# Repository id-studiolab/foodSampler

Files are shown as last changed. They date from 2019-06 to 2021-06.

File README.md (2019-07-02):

# foodSampler
Food sampler is a project to collect user data about their food consumption.
It consist of a series of devices equipped with buttons who can send and save data to a server using Lora protocol.

## The device
The devices are based on adafruit feather lora baord, and make use of a custom pcb.
They run on buttery and try to send messages to the lora network every 10 minutes.
once a button is pressed, they connect to the server and send out the data. A button cannot be pressed continuosly... a trasmission need to finish before a new message can be sent.
Arduino code, pcb design and more information on how to configure the library can be found inside the device folder.

## The server
The device communicate via a gateway to the things network, each device need to be configured and provisioned via ttn platform before it can send data to the server.
The server listens for incoming messages from the things network and saves the data to a mongodb DB. The data are accessible trough rest api.
More information on how to deploy the server and which api are accessible can be found in the server folder.

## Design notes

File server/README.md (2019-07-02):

# foodsempler
a node js server exposing rest api.

- use `npm install` to install the dependencies

- run the server with `npm run dev`

- update the apidoc using `gulp generateDoc`

- deploy to heroku with `git subtree push --prefix server/foodsampler/ heroku master`

## Usage
- Check [https://foodsampler.herokuapp.com/doc](https://foodsampler.herokuapp.com/doc) for a list of accessible api.
- All api requires the user to get an authorization token via the login api.
- The sign-up api is currently disabled, only the system administrator can create new accounts by re-enablyng the sign-up api and usin it to add new users to the DB.

## How to get the system ready for testing.
- use the api to create a new home.
- use the api to create new devices, make sure you define in which home the device will be added to

## How to chech the server logs
- login to heroku console and check if there are any error in the [console](https://dashboard.heroku.com/apps/foodsampler/logs)

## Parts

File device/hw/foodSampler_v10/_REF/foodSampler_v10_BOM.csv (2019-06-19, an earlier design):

Id | Designator | Package | Quantity | Designation | Supplier and ref
1 | J00 | PinHeader_1x16_P2.54mm_Vertical_SMD_Pin1Left | 1 | Conn_01x16
2 | C10,C20,C30,C40,C50,C60,C70,C80 | C_0603_1608Metric | 8 | 100nF
3 | R10,R20,R30,R40,R50,R60,R70,R03,R82,R04 | R_0603_1608Metric | 10 | 10K
4 | R11,R21,R31,R41,R51,R61,R71 | R_0603_1608Metric | 7 | 82R
5 | SW10,SW20,SW30,SW40,SW50,SW60,SW70 | MICRO_SW_LED | 7 | SWITCH_SPST_LED
6 | REF** | LIPO_3V7_2A_50x60 | 1 | LIPO_3V7_2A_50x60
7 | J01 | PinHeader_1x12_P2.54mm_Vertical_SMD_Pin1Left | 1 | Conn_01x12
8 | R80,R81 | R_0603_1608Metric | 2 | 4K7
9 | U80 | SOIC-8_3.9x4.9mm_P1.27mm | 1 | DS3231MZ
10 | D00 | LED_1206_3216Metric | 1 | LED_Small
11 | BT80 | CH291-1220LF | 1 | Battery_Cell
12 | Q00 | SOT-23 | 1 | BSS138
13 | REF**,REF**,REF**,REF** | MountingHole_3.2mm_M3_DIN965 | 4 | MountingHole_3.2mm_M3_DIN965
14 | REF**,REF** | Fiducial_1mm_Dia_2.54mm_Outer_CopperBottom | 2 | Fiducial_1mm_Dia_2.54mm_Outer_CopperBottom
15 | G*** | TUDelft_15x5.9 | 1 | LOGO
16 | REF** | OSHW-Logo_11.4x12mm_SilkScreen | 1 | OSHW-Logo_11.4x12mm_SilkScreen
17 | G*** | TUDelft_22.5x8.8 | 1 | LOGO

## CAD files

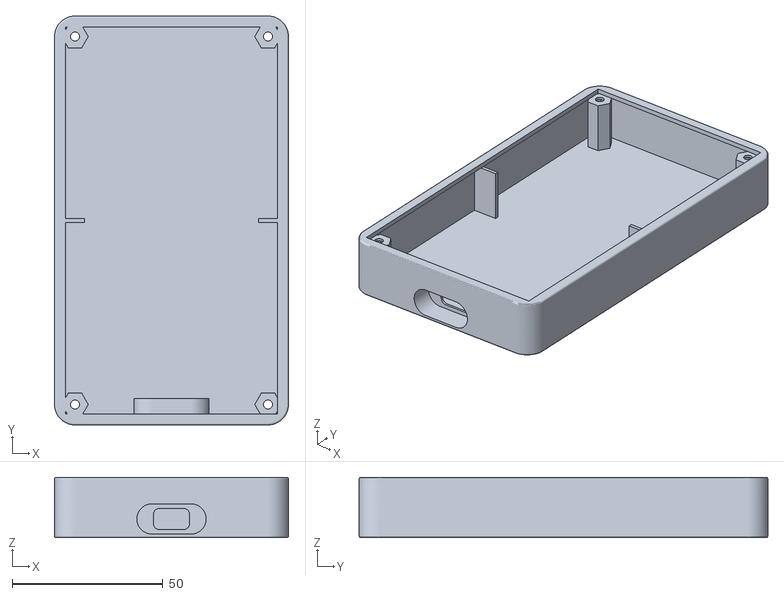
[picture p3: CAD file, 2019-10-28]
device/case/rev3.stl
77.6 x 135.6 x 20.0

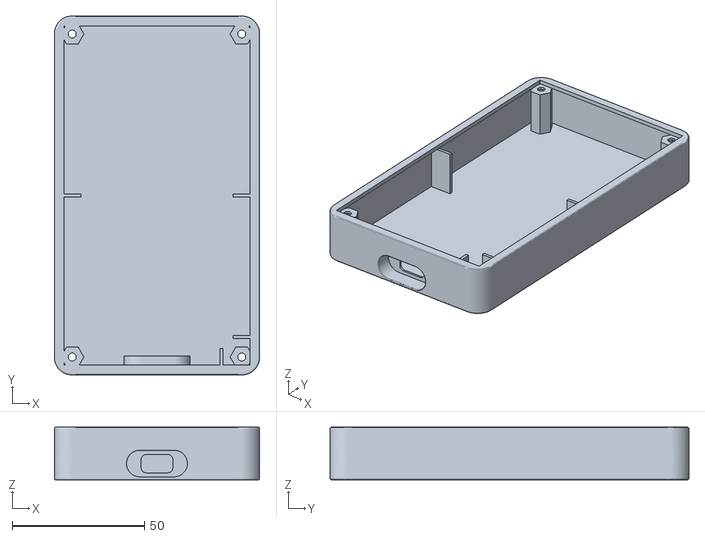
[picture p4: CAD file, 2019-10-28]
device/case/rev3c.stl
77.6 x 135.6 x 20.0

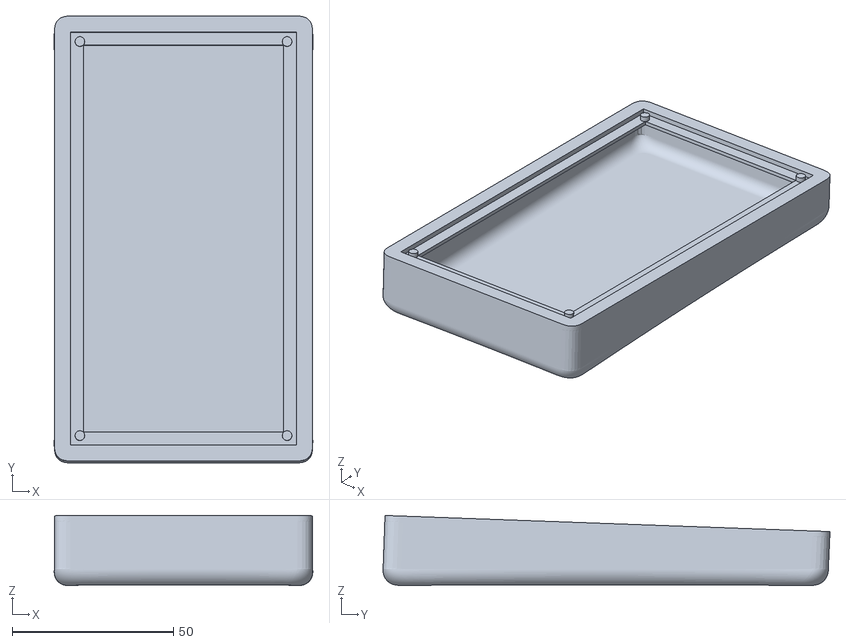
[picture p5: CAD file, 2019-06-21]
device/case/foodsampler.stl
80.1 x 138.5 x 21.7

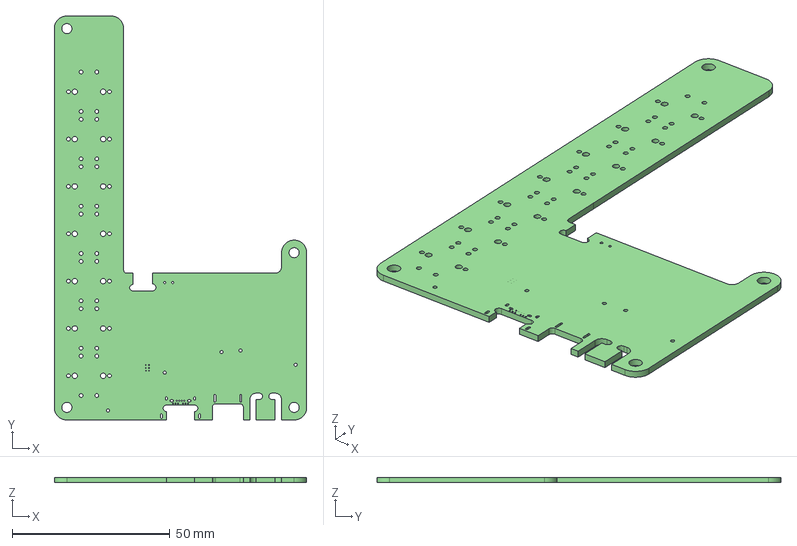
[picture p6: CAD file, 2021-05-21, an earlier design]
device/hw/foodSampler_v21/_REF/foodSampler_v21.step
80.0 x 128.0 x 1.60 mm

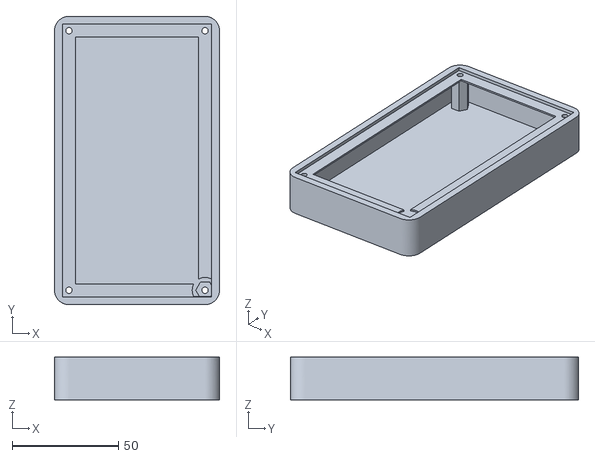
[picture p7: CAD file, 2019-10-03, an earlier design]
device/case/rev2.stl
77.6 x 135.6 x 20.0

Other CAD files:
device/case/rev3b.stl
device/case/rev3c.3dm

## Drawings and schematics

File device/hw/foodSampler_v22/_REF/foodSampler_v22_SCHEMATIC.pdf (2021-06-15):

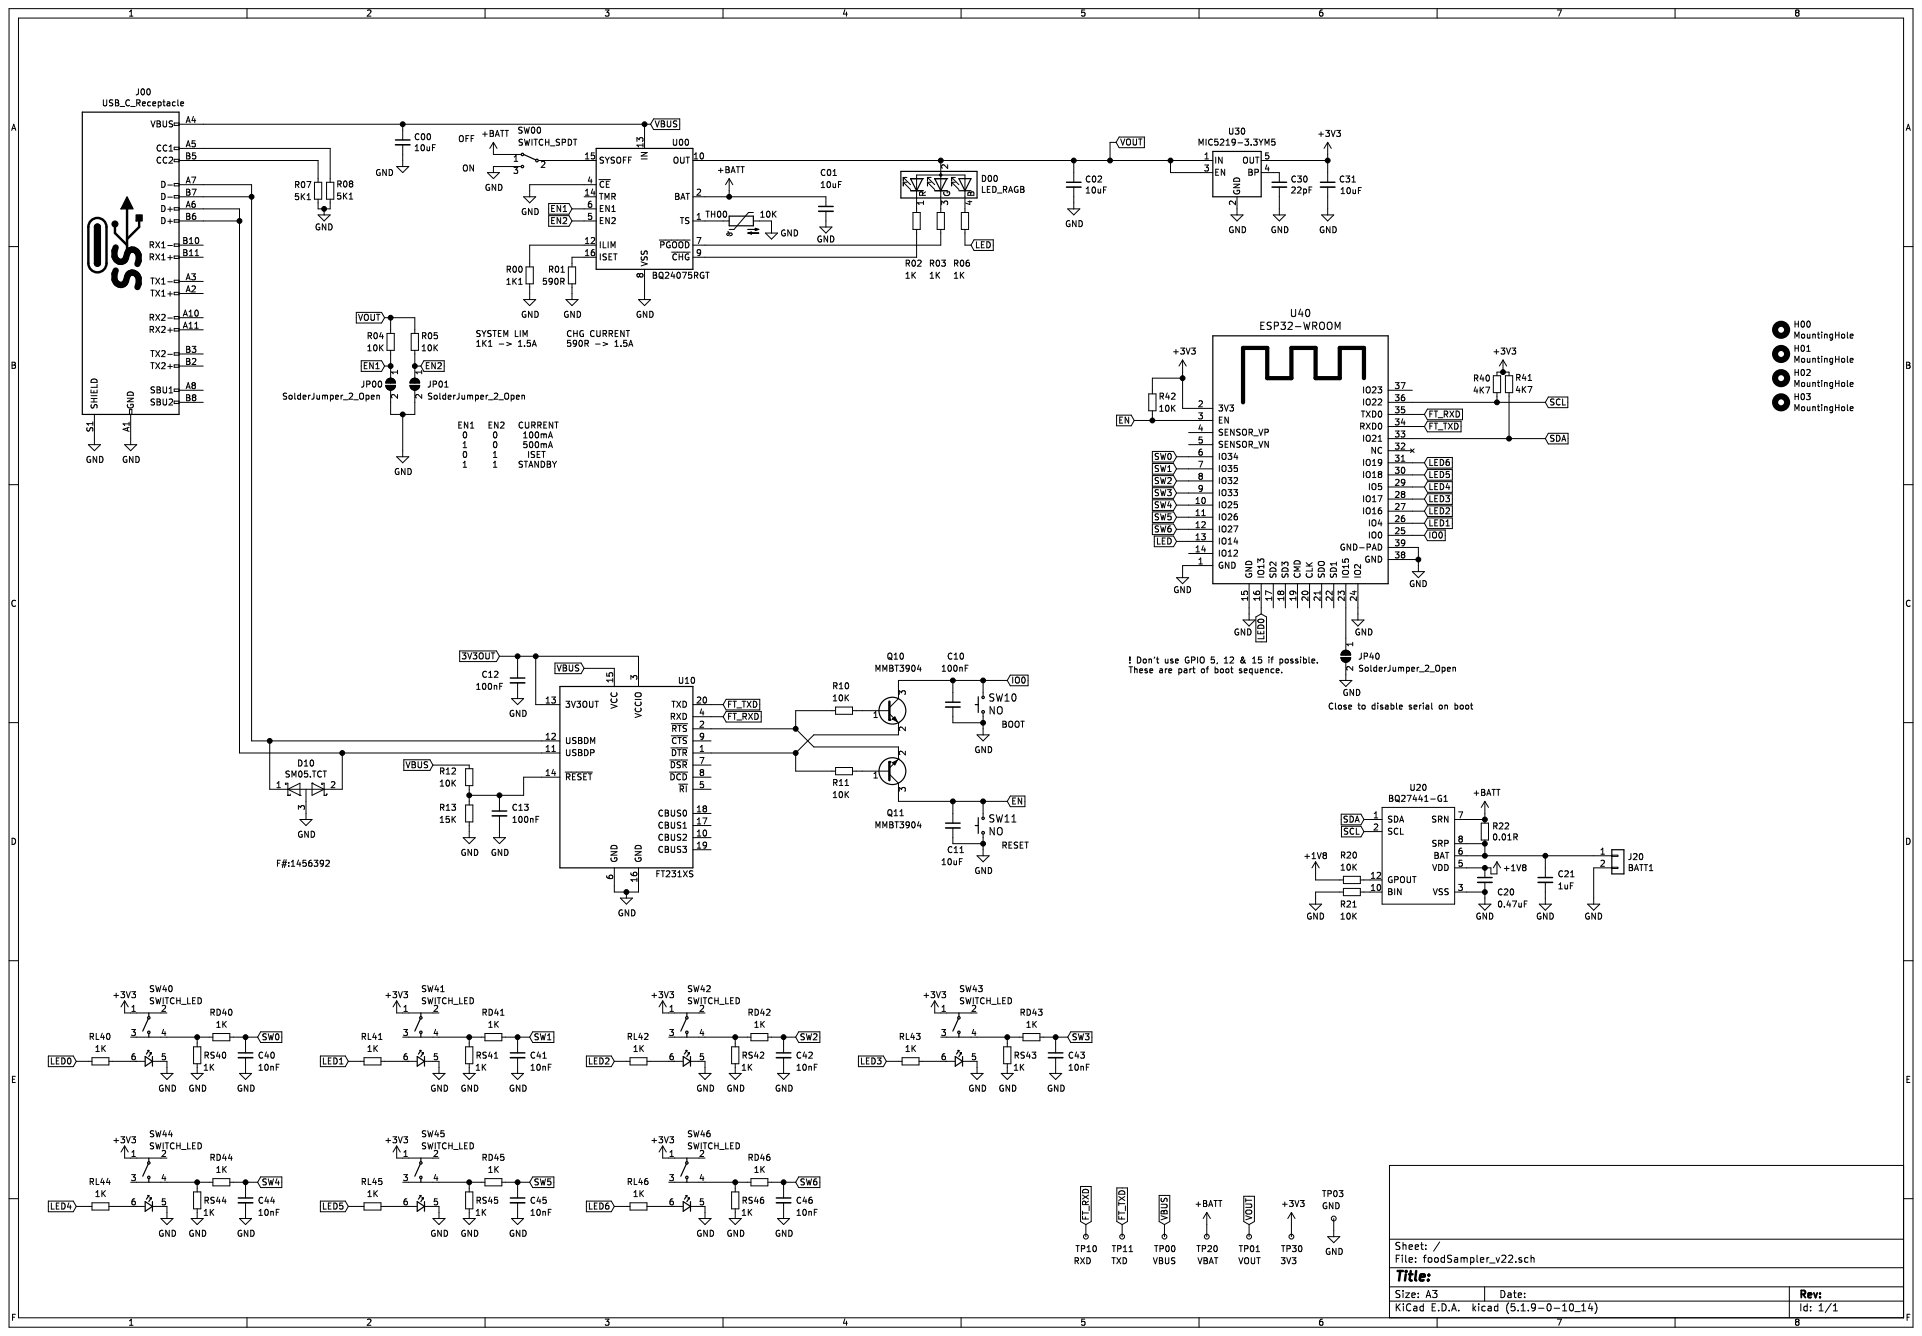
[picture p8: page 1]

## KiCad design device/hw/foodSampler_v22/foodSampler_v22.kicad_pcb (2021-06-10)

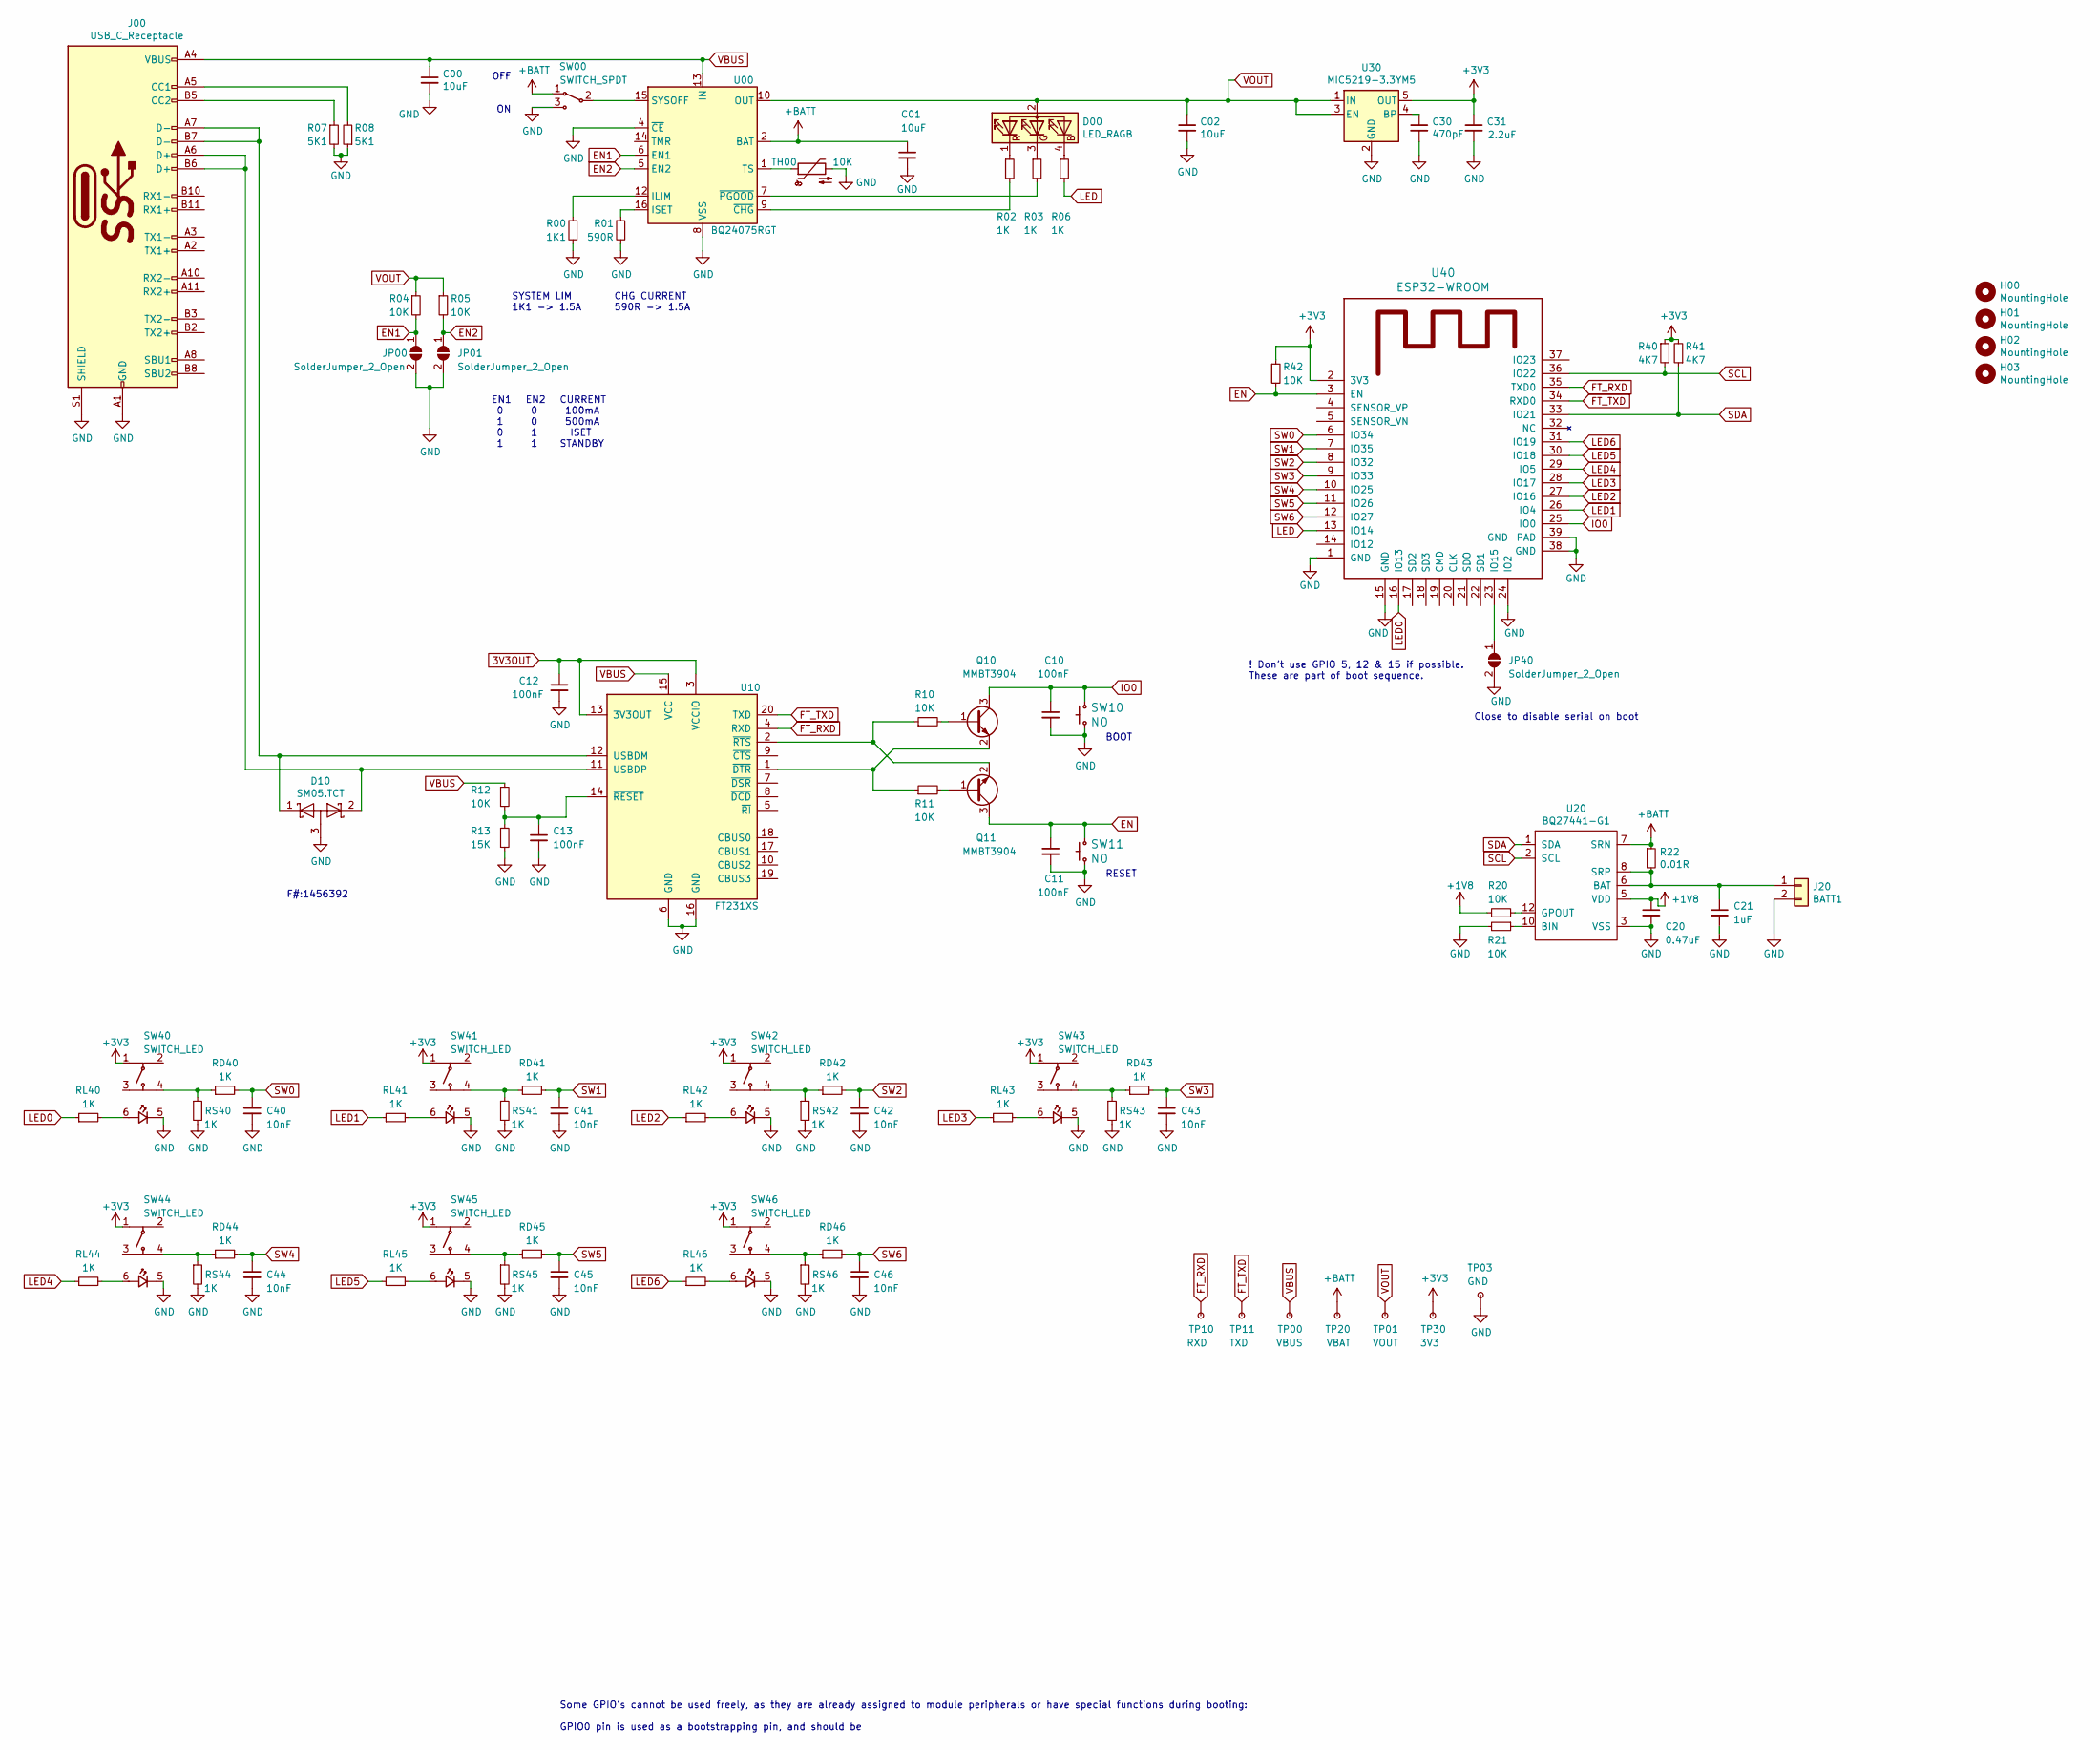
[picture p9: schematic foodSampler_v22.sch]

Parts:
C00, C01, C02: 10uF; C_0805_2012Metric
C10, C11, C12, C13: 100nF; C_0603_1608Metric
C20: 0.47uF; C_0603_1608Metric
C21: 1uF; C_0603_1608Metric
C30: 470pF; C_0603_1608Metric
C31: 2.2uF; CP_EIA-3216-10_Kemet-I
C40, C41, C42, C43, C44, C45, C46: 10nF; C_0603_1608Metric
D00: LED_RAGB; SMD_RGB_SIDE-APFA3010LSEEZGKQBKC
D10: SM05.TCT; SOT-23
H00, H01, H02, H03: MountingHole; MountingHole_3.2mm_M3
J00: USB_C_Receptacle; 632723130112
J20: BATT1; JST_B2B-PH-K-S_SUNK
JP00, JP01, JP40: SolderJumper_2_Open; SolderJumper-2_P1.3mm_Open_RoundedPad1.0x1.5mm
Q10, Q11: MMBT3904; SOT-23
R00: 1K1; R_0603_1608Metric
R01: 590R; R_0603_1608Metric
R02, R03, R06: 1K; R_0603_1608Metric
R04, R05, R10, R11, R12, R20, R21, R42: 10K; R_0603_1608Metric
R07, R08: 5K1; R_0603_1608Metric
R13: 15K; R_0603_1608Metric
R22: 0.01R; R_1210_3225Metric
R40, R41: 4K7; R_0603_1608Metric
RD40, RD41, RD42, RD43, RD44, RD45, RD46: 1K; R_0603_1608Metric
RL40, RL41, RL42, RL43, RL44, RL45, RL46: 1K; R_0603_1608Metric
RS40, RS41, RS42, RS43, RS44, RS45, RS46: 1K; R_0603_1608Metric
SW00: SWITCH_SPDT; DT-SC12P-BQR
SW10, SW11: NO; SW_SPST_4x3
SW40, SW41, SW42, SW43, SW44, SW45, SW46: SWITCH_LED; MICRO_SW_LED
TH00: 10K; R_Axial_DIN0204_L3.6mm_D1.6mm_P2.54mm_Vertical
TP00: VBUS; TEST_PAD_HOLE_1mm
TP01: VOUT; TEST_PAD_HOLE_1mm
TP03: GND; TEST_PAD_HOLE_1mm
TP10: RXD; TEST_PAD_HOLE_1mm
TP11: TXD; TEST_PAD_HOLE_1mm
TP20: VBAT; TEST_PAD_HOLE_1mm
TP30: 3V3; TEST_PAD_HOLE_1mm
U00: BQ24075RGT; VQFN-16-1EP_3x3mm_P0.5mm_EP1.6x1.6mm
U10: FT231XS; SSOP-20_3.9x8.7mm_P0.635mm
U20: BQ27441-G1; Texas_S-PDSO-N12
U30: MIC5219-3.3YM5; SOT-23-5
U40: ESP32-WROOM; ESP32-WROOM-32

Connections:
3V3OUT: C12.1, U10.3 (VCCIO), U10.13 (3V3OUT)
+1V8: C20.1, R20.1, U20.5 (VDD)
+3V3: C31.1, R40.1, R41.2, R42.1, SW40.1, SW41.1, SW42.1, SW43.1, SW44.1, SW45.1, SW46.1, TP30.1, U30.5 (OUT), U40.2 (3V3)
+BATT: C01.1, R22.1, SW00.1, TP20.1, U00.2 (BAT), U00.3 (BAT), U20.7 (SRN)
EN: C11.1, Q11.3 (C), R42.2, SW11.2 (B0), U40.3 (EN)
EN1: JP00.1 (A), R04.2, U00.6 (EN1)
EN2: JP01.1 (A), R05.2, U00.5 (EN2)
FT_RXD: TP10.1, U10.4 (RXD), U40.35 (TXD0)
FT_TXD: TP11.1, U10.20 (TXD), U40.34 (RXD0)
GND: C00.2, C01.2, C02.2, C10.2, C11.2, C12.2, C13.2, C20.2, C21.2, C30.2, C31.2, C40.2, C41.2, C42.2, C43.2, C44.2, C45.2, C46.2, D10.3 (A), J00.A1 (GND), J00.A12 (GND), J00.B1 (GND), J00.B12 (GND), J00.S1 (SHIELD), J20.2, JP00.2 (B), JP01.2 (B), JP40.2 (B), R00.2, R01.2, R07.2, R08.1, R13.2, R21.2, RS40.2, RS41.2, RS42.2, RS43.2, RS44.2, RS45.2, RS46.2, SW00.3, SW10.1 (A0), SW11.1 (A0), SW40.5, SW41.5, SW42.5, SW43.5, SW44.5, SW45.5, SW46.5, TH00.2, TP03.1, U00.4 (~CE), U00.8 (VSS), U00.17 (VSS), U10.6 (GND), U10.16 (GND), U20.3 (VSS), U30.2 (GND), U40.1 (GND), U40.15 (GND), U40.24 (IO2), U40.38 (GND), U40.39 (GND-PAD)
IO0: C10.1, Q10.3 (C), SW10.2 (B0), U40.25 (IO0)
LED: R06.2, U40.13 (IO14)
LED0: RL40.1, U40.16 (IO13)
LED1: RL41.1, U40.26 (IO4)
LED2: RL42.1, U40.27 (IO16)
LED3: RL43.1, U40.28 (IO17)
LED4: RL44.1, U40.29 (IO5)
LED5: RL45.1, U40.30 (IO18)
LED6: RL46.1, U40.31 (IO19)
unnamed: C13.1, R12.2, R13.1, U10.14 (~RESET)
unnamed: C21.1, J20.1, R22.2, U20.6 (BAT), U20.8 (SRP)
unnamed: C30.1, U30.4 (BP)
unnamed: D00.1 (RK), R02.1
unnamed: D00.3 (GK), R03.1
unnamed: D00.4 (BK), R06.1
unnamed: D10.1 (K), J00.A7 (D-), J00.B7 (D-), U10.12 (USBDM)
unnamed: D10.2 (K), J00.A6 (D+), J00.B6 (D+), U10.11 (USBDP)
unnamed: J00.A5 (CC1), R08.2
unnamed: J00.B5 (CC2), R07.1
unnamed: JP40.1 (A), U40.23 (IO15)
unnamed: Q10.1 (B), R10.2
unnamed: Q10.2 (E), R11.1, U10.1 (~DTR)
unnamed: Q11.1 (B), R11.2
unnamed: Q11.2 (E), R10.1, U10.2 (~RTS)
unnamed: R00.1, U00.12 (ILIM)
unnamed: R01.1, U00.16 (ISET)
unnamed: R02.2, U00.9 (~CHG)
unnamed: R03.2, U00.7 (~PGOOD)
unnamed: R20.2, U20.12 (GPOUT)
unnamed: R21.1, U20.10 (BIN)
unnamed: RD40.1, RS40.1, SW40.4
unnamed: RD41.1, RS41.1, SW41.4
unnamed: RD42.1, RS42.1, SW42.4
unnamed: RD43.1, RS43.1, SW43.4
unnamed: RD44.1, RS44.1, SW44.4
unnamed: RD45.1, RS45.1, SW45.4
unnamed: RD46.1, RS46.1, SW46.4
unnamed: RL40.2, SW40.6
unnamed: RL41.2, SW41.6
unnamed: RL42.2, SW42.6
unnamed: RL43.2, SW43.6
unnamed: RL44.2, SW44.6
unnamed: RL45.2, SW45.6
unnamed: RL46.2, SW46.6
unnamed: SW00.2, U00.15 (SYSOFF)
unnamed: TH00.1, U00.1 (TS)
SCL: R40.2, U20.2 (SCL), U40.36 (IO22)
SDA: R41.1, U20.1 (SDA), U40.33 (IO21)
SW0: C40.1, RD40.2, U40.6 (IO34)
SW1: C41.1, RD41.2, U40.7 (IO35)
SW2: C42.1, RD42.2, U40.8 (IO32)
SW3: C43.1, RD43.2, U40.9 (IO33)
SW4: C44.1, RD44.2, U40.10 (IO25)
SW5: C45.1, RD45.2, U40.11 (IO26)
SW6: C46.1, RD46.2, U40.12 (IO27)
VBUS: C00.1, J00.A4 (VBUS), J00.A9 (VBUS), J00.B4 (VBUS), J00.B9 (VBUS), R12.1, TP00.1, U00.13 (IN), U10.15 (VCC)
VOUT: C02.1, D00.2 (A), R04.1, R05.1, TP01.1, U00.10 (OUT), U00.11 (OUT), U30.1 (IN), U30.3 (EN)

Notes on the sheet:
F#:1456392
RESET
BOOT
! Don’t use GPIO 5, 12 & 15 if possible. These are part of boot sequence.
CHG CURRENT 590R -> 1.5A
SYSTEM LIM 1K1 -> 1.5A
EN1 0 1 0 1
EN2 0 0 1 1
CURRENT 100mA 500mA ISET STANDBY
OFF ON
Some GPIO’s cannot be used freely, as they are already assigned to module peripherals or have special functions during booting: GPIO0 pin is used as a bootstrapping pin, and should be low to enter UART download mode. Make sure it is not pulled low by a peripheral device during boot or the firmware 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
Close to disable serial on boot

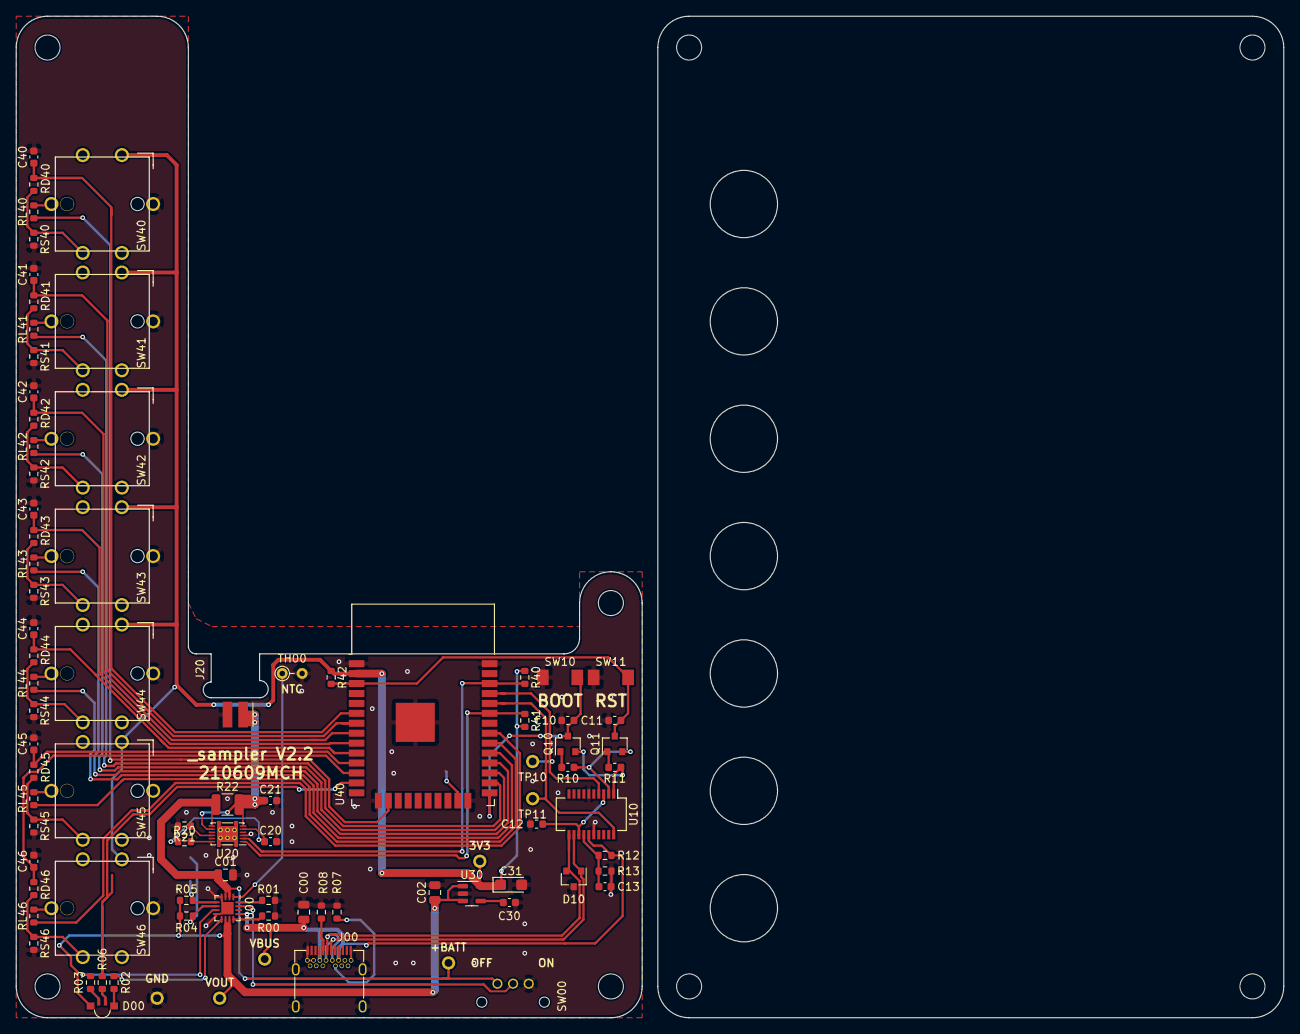
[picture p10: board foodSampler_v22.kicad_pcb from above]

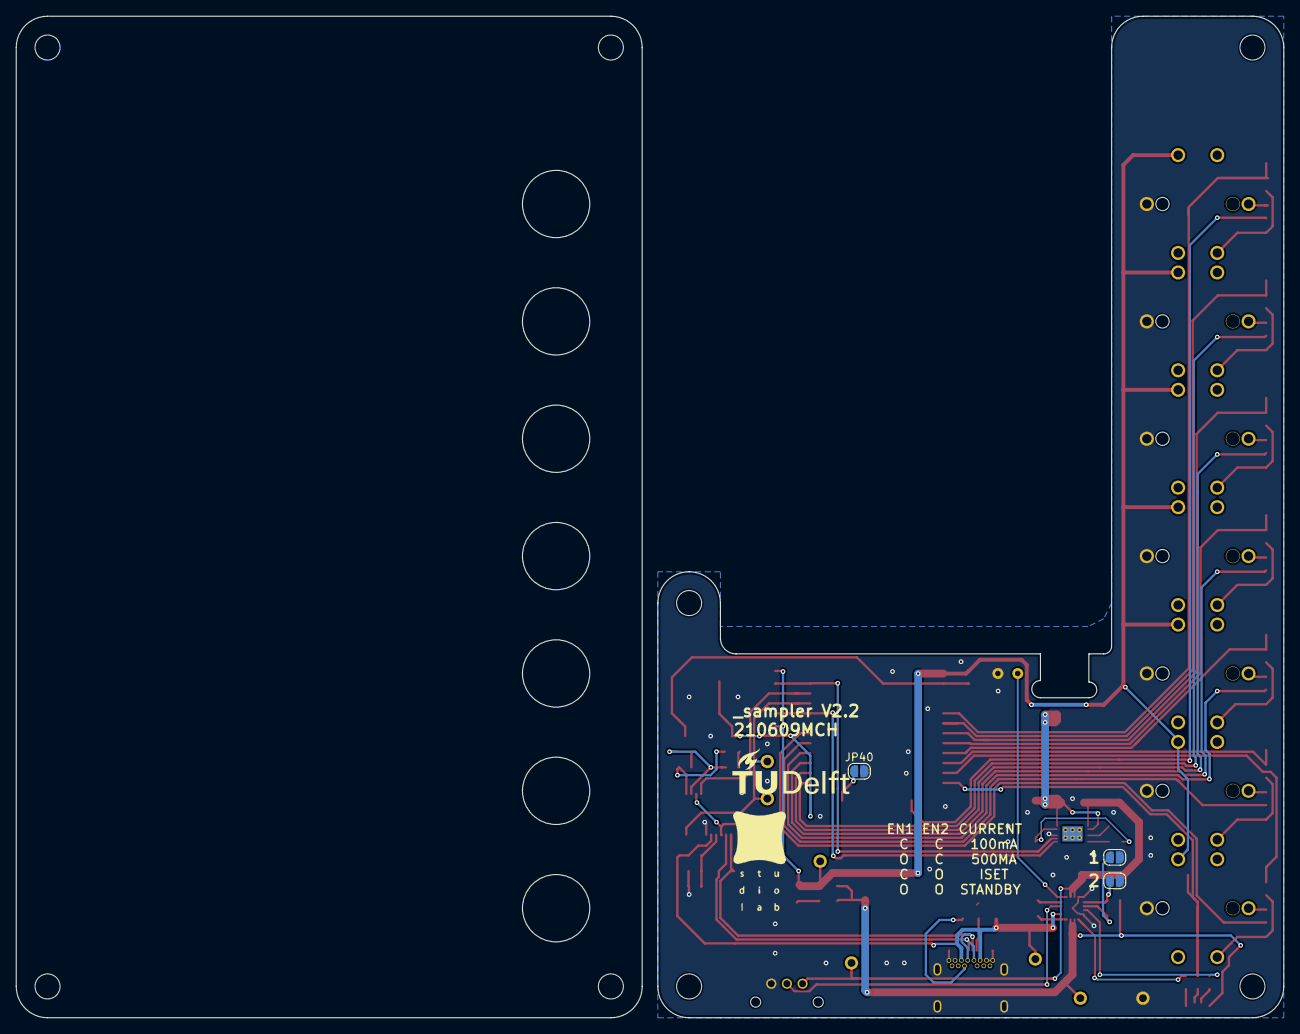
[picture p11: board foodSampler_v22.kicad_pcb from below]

Board: 2 copper layers, 162.0 x 128.0 mm, 98 parts (3 on the bottom side), 67 nets.

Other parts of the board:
H01#2, H01#3, H01#4, H01#5: MountingHole; MountingHole_3.2mm_M3

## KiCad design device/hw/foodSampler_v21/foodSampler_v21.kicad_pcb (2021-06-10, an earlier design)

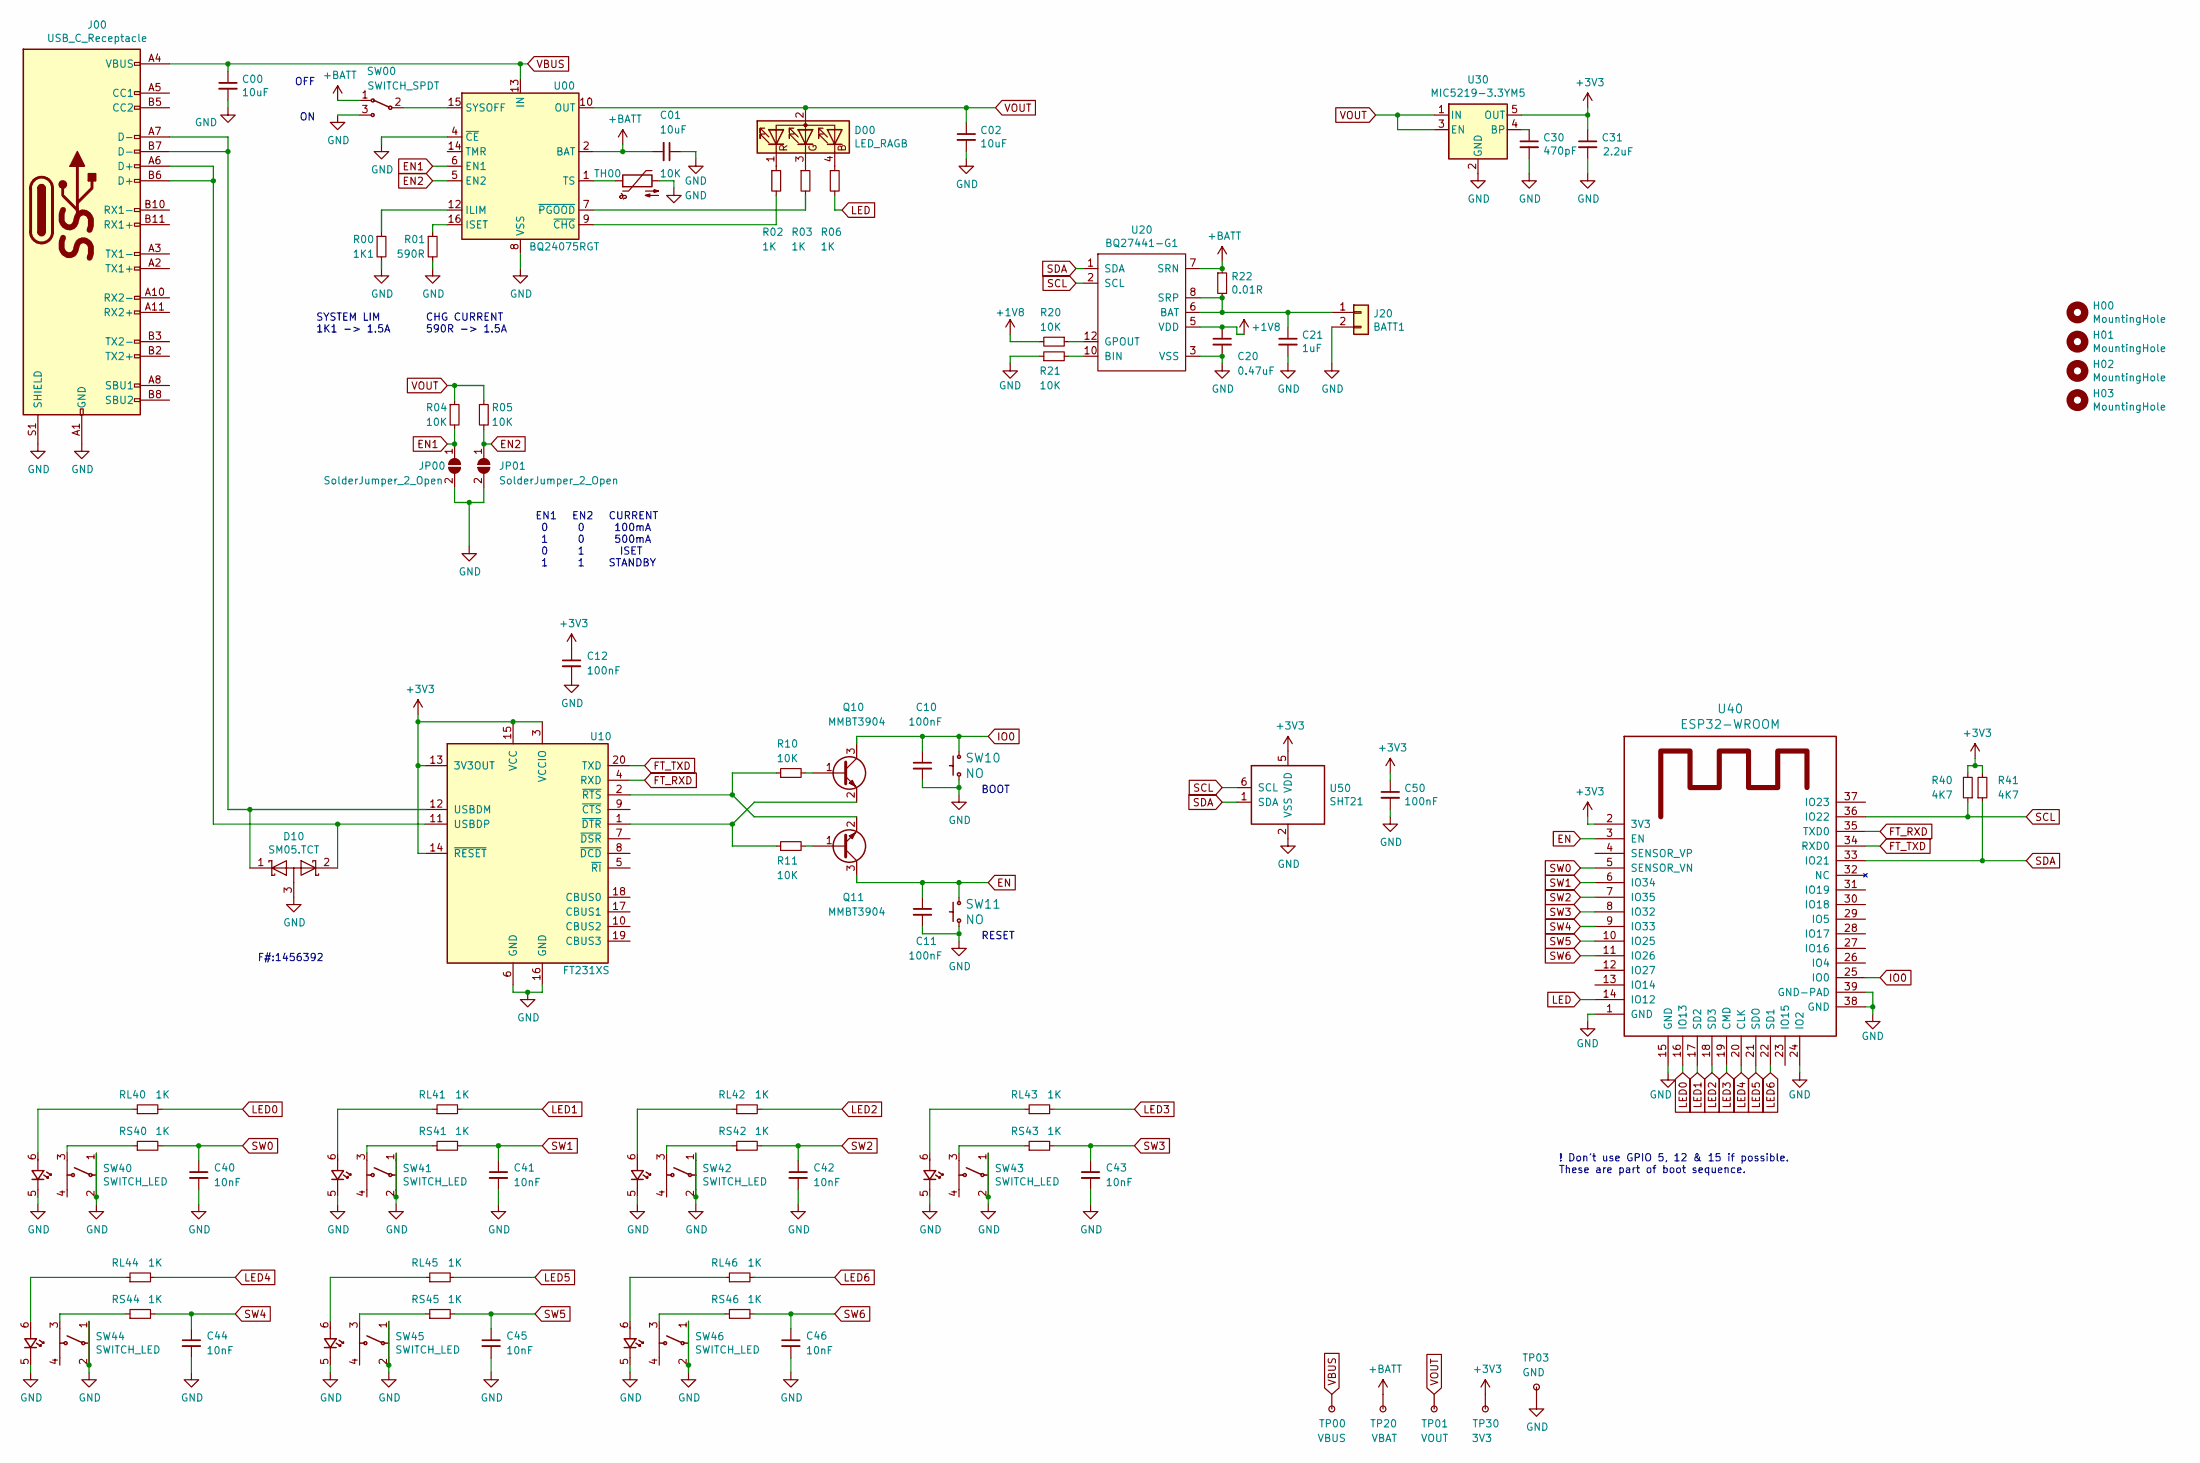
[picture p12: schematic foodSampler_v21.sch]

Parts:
C00, C01, C02: 10uF; C_0805_2012Metric
C10, C11, C12, C50: 100nF; C_0603_1608Metric
C20: 0.47uF; C_0603_1608Metric
C21: 1uF; C_0603_1608Metric
C30: 470pF; C_0603_1608Metric
C31: 2.2uF; CP_EIA-3216-10_Kemet-I
C40, C41, C42, C43, C44, C45, C46: 10nF; C_0603_1608Metric
D00: LED_RAGB; SMD_RGB_SIDE-APFA3010LSEEZGKQBKC
D10: SM05.TCT; SOT-23
H00, H01, H02, H03: MountingHole; MountingHole_3.2mm_M3
J00: USB_C_Receptacle; CUI_USB-C_UJ31-CH-3-MSMT-TR-67
J20: BATT1; JST_B2B-PH-K-S_SUNK
JP00, JP01: SolderJumper_2_Open; SolderJumper-2_P1.3mm_Open_RoundedPad1.0x1.5mm
Q10, Q11: MMBT3904; SOT-23
R00: 1K1; R_0603_1608Metric
R01: 590R; R_0603_1608Metric
R02, R03, R06: 1K; R_0603_1608Metric
R04, R05, R10, R11, R20, R21: 10K; R_0603_1608Metric
R22: 0.01R; C_1206_3216Metric
R40, R41: 4K7; R_0603_1608Metric
RL40, RL41, RL42, RL43, RL44, RL45, RL46: 1K; R_0603_1608Metric
RS40, RS41, RS42, RS43, RS44, RS45, RS46: 1K; R_0603_1608Metric
SW00: SWITCH_SPDT; C&K-OS102011MS2QN1_side_mount
SW10, SW11: NO; SW_SPST_4x3
SW40, SW41, SW42, SW43, SW44, SW45, SW46: SWITCH_LED; MICRO_SW_LED
TH00: 10K; R_Axial_DIN0204_L3.6mm_D1.6mm_P2.54mm_Vertical
TP00: VBUS; TEST_PAD_HOLE_1mm
TP01: VOUT; TEST_PAD_HOLE_1mm
TP03: GND; TEST_PAD_HOLE_1mm
TP20: VBAT; TEST_PAD_HOLE_1mm
TP30: 3V3; TEST_PAD_HOLE_1mm
U00: BQ24075RGT; VQFN-16-1EP_3x3mm_P0.5mm_EP1.6x1.6mm
U10: FT231XS; SSOP-20_3.9x8.7mm_P0.635mm
U20: BQ27441-G1; Texas_S-PDSO-N12
U30: MIC5219-3.3YM5; SOT-23-5
U40: ESP32-WROOM; ESP32-WROOM-32
U50: SHT21

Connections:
+1V8: C20.1, R20.2, U20.5 (VDD)
+3V3: C12.1, C31.1, C50.1, R40.2, R41.2, TP30.1, U10.3 (VCCIO), U10.13 (3V3OUT), U10.14 (~RESET), U10.15 (VCC), U30.5 (OUT), U40.2 (3V3), U50.5 (VDD)
+BATT: C01.2, R22.1, SW00.1, TP20.1, U00.2 (BAT), U00.3 (BAT), U20.7 (SRN)
EN: C11.1, Q11.3 (C), SW11.2 (B0), U40.3 (EN)
EN1: JP00.1 (A), R04.2, U00.6 (EN1)
EN2: JP01.1 (A), R05.2, U00.5 (EN2)
FT_RXD: U10.4 (RXD), U40.35 (TXD0)
FT_TXD: U10.20 (TXD), U40.34 (RXD0)
GND: C00.2, C01.1, C02.2, C10.2, C11.2, C12.2, C20.2, C21.2, C30.2, C31.2, C40.2, C41.2, C42.2, C43.2, C44.2, C45.2, C46.2, C50.2, D10.3 (A), J00.A1 (GND), J00.A12 (GND), J00.B1 (GND), J00.B12 (GND), J00.S1 (SHIELD), J20.2, JP00.2 (B), JP01.2 (B), R00.2, R01.2, R21.1, SW00.3, SW10.1 (A0), SW11.1 (A0), SW40.1, SW40.2, SW40.5, SW41.1, SW41.2, SW41.5, SW42.1, SW42.2, SW42.5, SW43.1, SW43.2, SW43.5, SW44.1, SW44.2, SW44.5, SW45.1, SW45.2, SW45.5, SW46.1, SW46.2, SW46.5, TH00.2, TP03.1, U00.4 (~CE), U00.8 (VSS), U00.17 (VSS), U10.6 (GND), U10.16 (GND), U20.3 (VSS), U30.2 (GND), U40.1 (GND), U40.15 (GND), U40.24 (IO2), U40.38 (GND), U40.39 (GND-PAD), U50.2 (VSS)
IO0: C10.1, Q10.3 (C), SW10.2 (B0), U40.25 (IO0)
LED: R06.2, U40.14 (IO12)
LED0: RL40.2, U40.16 (IO13)
LED1: RL41.2, U40.17 (SD2)
LED2: RL42.2, U40.18 (SD3)
LED3: RL43.2, U40.19 (CMD)
LED4: RL44.2, U40.20 (CLK)
LED5: RL45.2, U40.21 (SDO)
LED6: RL46.2, U40.22 (SD1)
unnamed: C21.1, J20.1, R22.2, U20.6 (BAT), U20.8 (SRP)
unnamed: C30.1, U30.4 (BP)
unnamed: D00.1 (RK), R02.1
unnamed: D00.3 (GK), R03.1
unnamed: D00.4 (BK), R06.1
unnamed: D10.1 (K), J00.A7 (D-), J00.B7 (D-), U10.12 (USBDM)
unnamed: D10.2 (K), J00.A6 (D+), J00.B6 (D+), U10.11 (USBDP)
unnamed: Q10.1 (B), R10.2
unnamed: Q10.2 (E), R11.1, U10.1 (~DTR)
unnamed: Q11.1 (B), R11.2
unnamed: Q11.2 (E), R10.1, U10.2 (~RTS)
unnamed: R00.1, U00.12 (ILIM)
unnamed: R01.1, U00.16 (ISET)
unnamed: R02.2, U00.9 (~CHG)
unnamed: R03.2, U00.7 (~PGOOD)
unnamed: R20.1, U20.12 (GPOUT)
unnamed: R21.2, U20.10 (BIN)
unnamed: RL40.1, SW40.6
unnamed: RL41.1, SW41.6
unnamed: RL42.1, SW42.6
unnamed: RL43.1, SW43.6
unnamed: RL44.1, SW44.6
unnamed: RL45.1, SW45.6
unnamed: RL46.1, SW46.6
unnamed: RS40.1, SW40.3
unnamed: RS41.1, SW41.3
unnamed: RS42.1, SW42.3
unnamed: RS43.1, SW43.3
unnamed: RS44.1, SW44.3
unnamed: RS45.1, SW45.3
unnamed: RS46.1, SW46.3
unnamed: SW00.2, U00.15 (SYSOFF)
unnamed: TH00.1, U00.1 (TS)
SCL: R40.1, U20.2 (SCL), U40.36 (IO22), U50.6 (SCL)
SDA: R41.1, U20.1 (SDA), U40.33 (IO21), U50.1 (SDA)
SW0: C40.1, RS40.2, U40.5 (SENSOR_VN)
SW1: C41.1, RS41.2, U40.6 (IO34)
SW2: C42.1, RS42.2, U40.7 (IO35)
SW3: C43.1, RS43.2, U40.8 (IO32)
SW4: C44.1, RS44.2, U40.9 (IO33)
SW5: C45.1, RS45.2, U40.10 (IO25)
SW6: C46.1, RS46.2, U40.11 (IO26)
VBUS: C00.1, J00.A4 (VBUS), J00.A9 (VBUS), J00.B4 (VBUS), J00.B9 (VBUS), TP00.1, U00.13 (IN)
VOUT: C02.1, D00.2 (A), R04.1, R05.1, TP01.1, U00.10 (OUT), U00.11 (OUT), U30.1 (IN), U30.3 (EN)

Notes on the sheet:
F#:1456392
RESET
BOOT
! Don’t use GPIO 5, 12 & 15 if possible. These are part of boot sequence.
CHG CURRENT 590R -> 1.5A
SYSTEM LIM 1K1 -> 1.5A
EN1 0 1 0 1
EN2 0 0 1 1
CURRENT 100mA 500mA ISET STANDBY
OFF ON

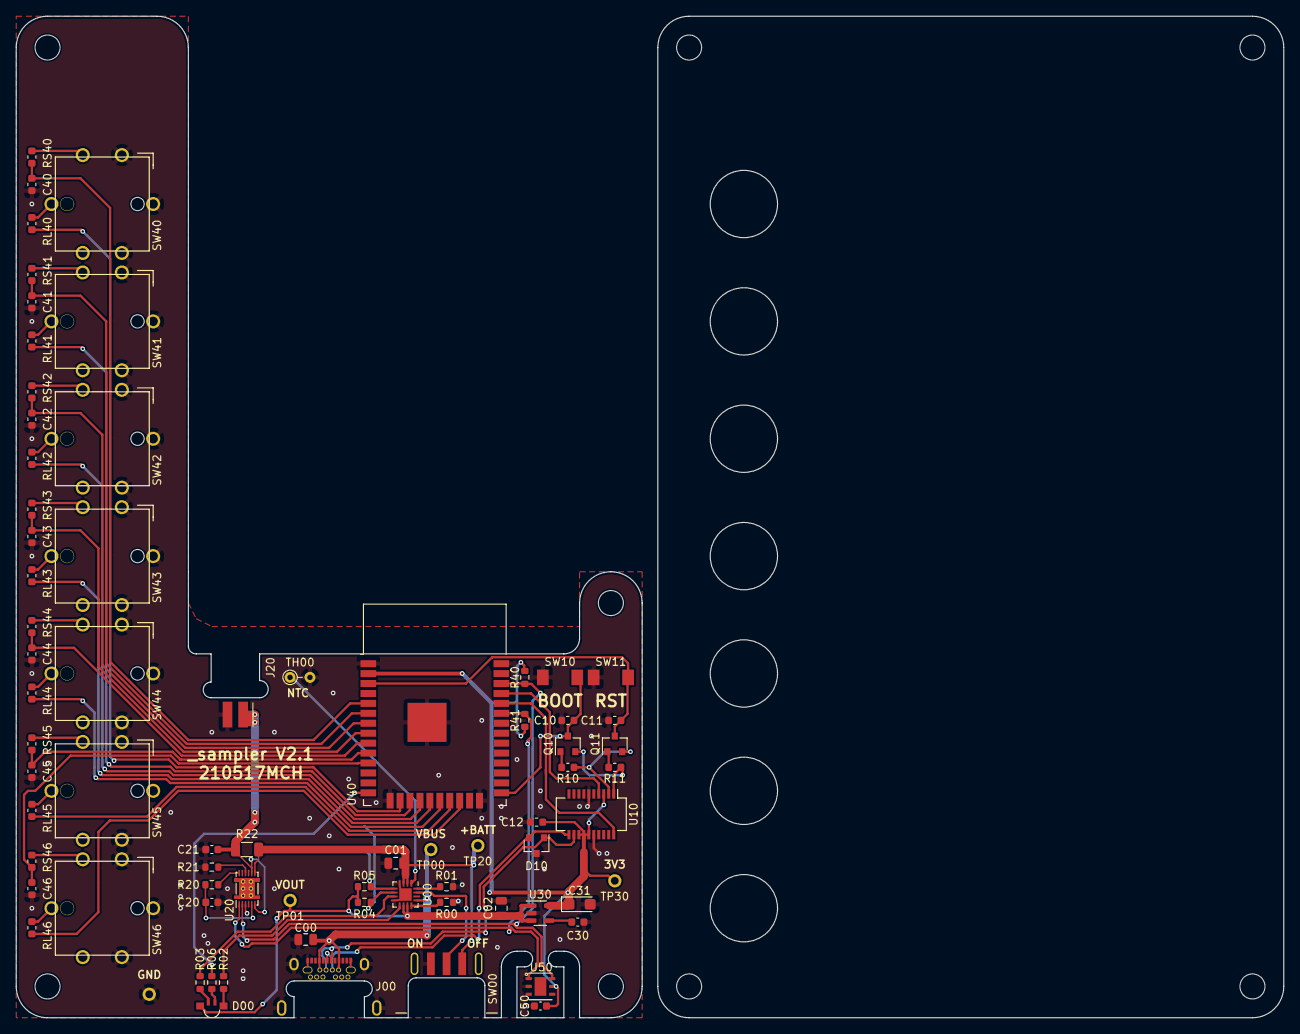
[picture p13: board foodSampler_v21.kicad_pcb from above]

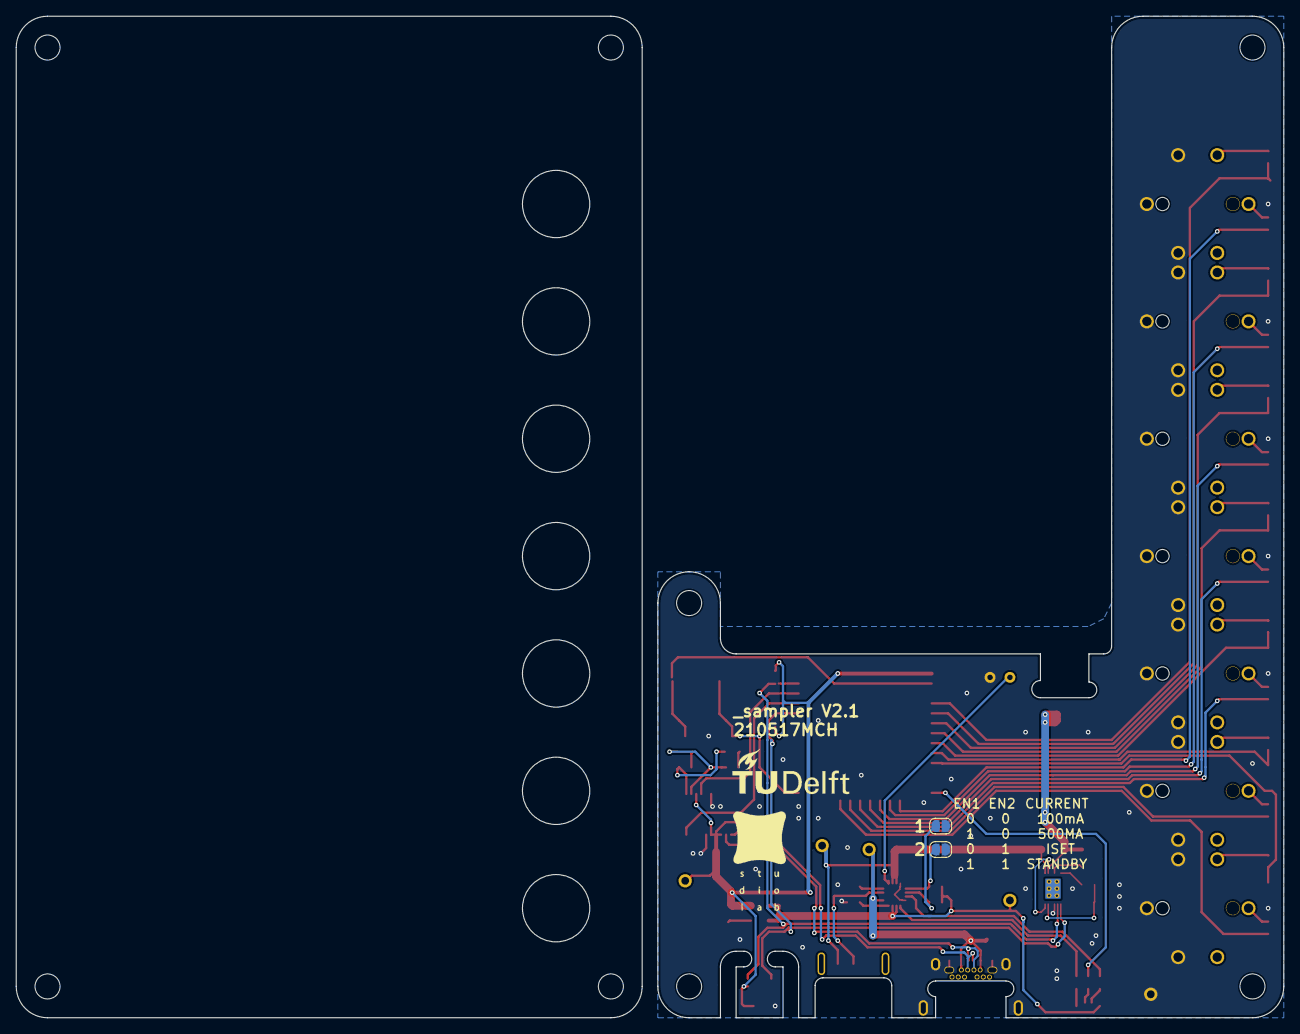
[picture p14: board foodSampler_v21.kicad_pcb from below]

Board: 2 copper layers, 162.0 x 128.0 mm, 84 parts (2 on the bottom side), 62 nets.

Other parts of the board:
H01#2, H01#3, H01#4, H01#5: MountingHole; MountingHole_3.2mm_M3

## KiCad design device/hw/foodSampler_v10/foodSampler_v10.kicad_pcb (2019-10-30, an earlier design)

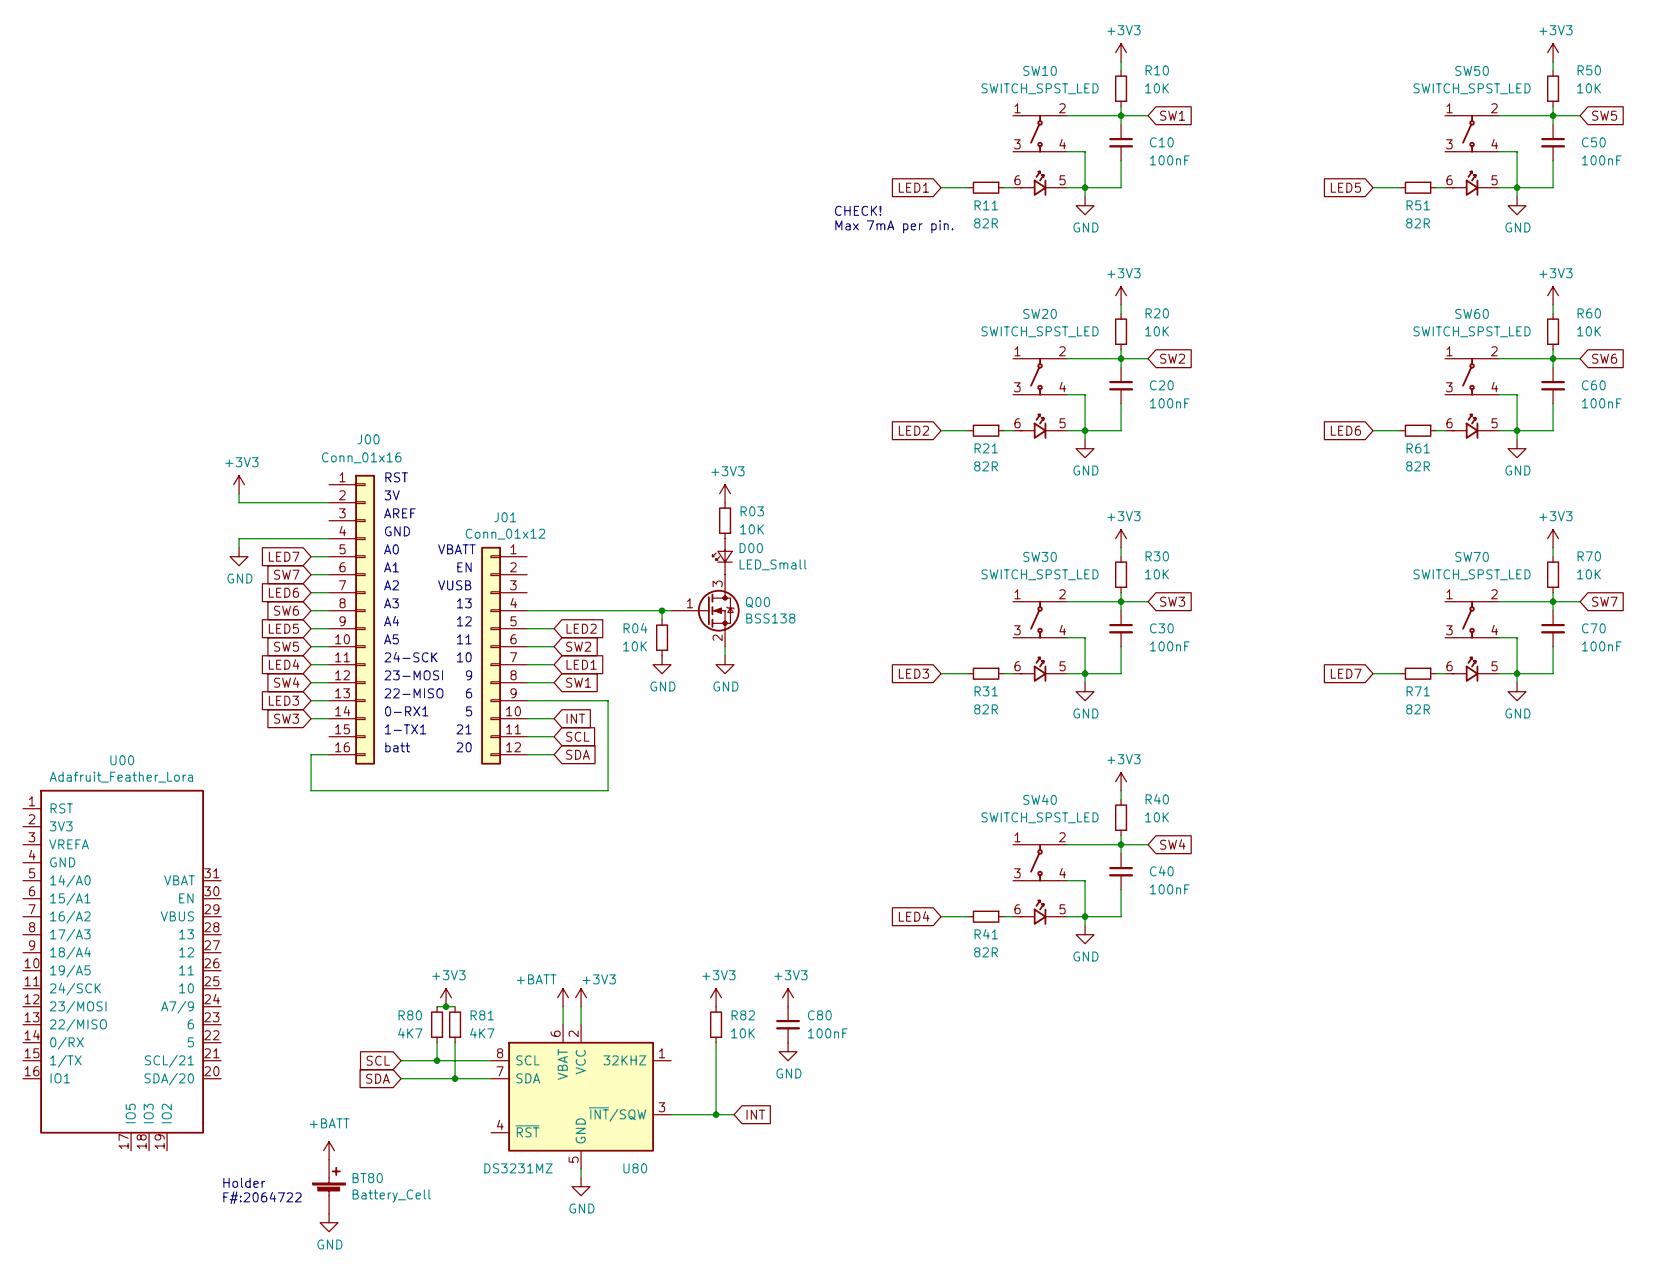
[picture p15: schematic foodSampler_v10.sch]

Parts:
BT80: Battery_Cell; CH291-1220LF
C10, C20, C30, C40, C50, C60, C70, C80: 100nF; C_0603_1608Metric
D00: LED_Small; LED_1206_3216Metric
J00: Conn_01x16; PinHeader_1x16_P2.54mm_Vertical_SMD_Pin1Left
J01: Conn_01x12; PinHeader_1x12_P2.54mm_Vertical_SMD_Pin1Left
Q00: BSS138; SOT-23
R03, R04, R10, R20, R30, R40, R50, R60, R70, R82: 10K; R_0603_1608Metric
R11, R21, R31, R41, R51, R61, R71: 82R; R_0603_1608Metric
R80, R81: 4K7; R_0603_1608Metric
SW10, SW20, SW30, SW40, SW50, SW60, SW70: SWITCH_SPST_LED; MICRO_SW_LED
U00: Adafruit_Feather_Lora; Adafruit Feather LORA
U80: DS3231MZ; SOIC-8_3.9x4.9mm_P1.27mm

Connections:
+3V3: C80.1, J00.2, R03.2, R10.2, R20.2, R30.2, R40.2, R50.2, R60.2, R70.2, R80.2, R81.2, R82.2, U80.2 (VCC)
+BATT: BT80.1 (+), U80.6 (VBAT)
GND: BT80.2 (-), C10.2, C20.2, C30.2, C40.2, C50.2, C60.2, C70.2, C80.2, J00.4, Q00.2 (S), R04.1, SW10.4, SW10.5, SW20.4, SW20.5, SW30.4, SW30.5, SW40.4, SW40.5, SW50.4, SW50.5, SW60.4, SW60.5, SW70.4, SW70.5, U80.5 (GND)
INT: J01.10, R82.1, U80.3 (~INT~/SQW)
LED1: J01.7, R11.2
LED2: J01.5, R21.2
LED3: J00.13, R31.2
LED4: J00.11, R41.2
LED5: J00.9, R51.2
LED6: J00.7, R61.2
LED7: J00.5, R71.2
unnamed: D00.1 (K), Q00.3 (D)
unnamed: D00.2 (A), R03.1
unnamed: J00.16, J01.9
unnamed: J01.4, Q00.1 (G), R04.2
unnamed: R11.1, SW10.6
unnamed: R21.1, SW20.6
unnamed: R31.1, SW30.6
unnamed: R41.1, SW40.6
unnamed: R51.1, SW50.6
unnamed: R61.1, SW60.6
unnamed: R71.1, SW70.6
SCL: J01.11, R80.1, U80.8 (SCL)
SDA: J01.12, R81.1, U80.7 (SDA)
SW1: C10.1, J01.8, R10.1, SW10.2
SW2: C20.1, J01.6, R20.1, SW20.2
SW3: C30.1, J00.14, R30.1, SW30.2
SW4: C40.1, J00.12, R40.1, SW40.2
SW5: C50.1, J00.10, R50.1, SW50.2
SW6: C60.1, J00.8, R60.1, SW60.2
SW7: C70.1, J00.6, R70.1, SW70.2

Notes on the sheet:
CHECK! Max 7mA per pin.
Holder F#:2064722
batt
1-TX1
0-RX1
22-MISO
23-MOSI
24-SCK
GND
AREF
RST
VUSB
VBATT

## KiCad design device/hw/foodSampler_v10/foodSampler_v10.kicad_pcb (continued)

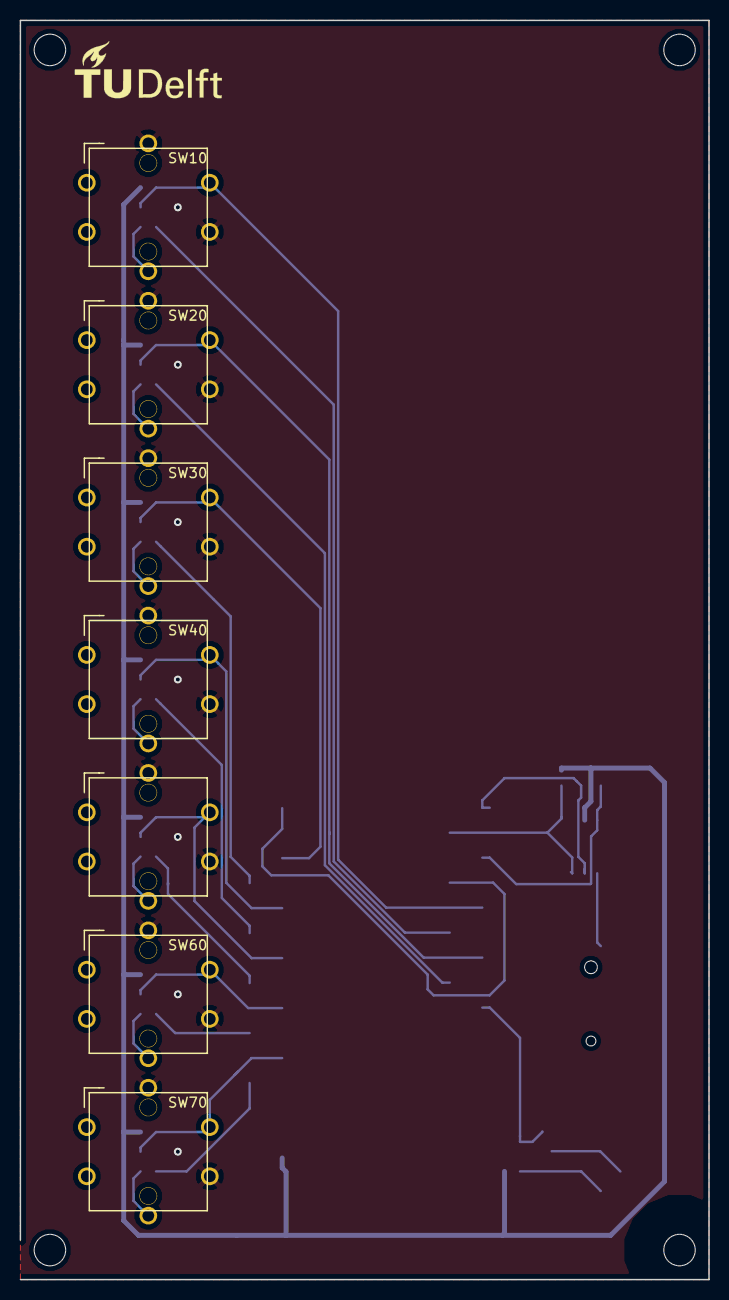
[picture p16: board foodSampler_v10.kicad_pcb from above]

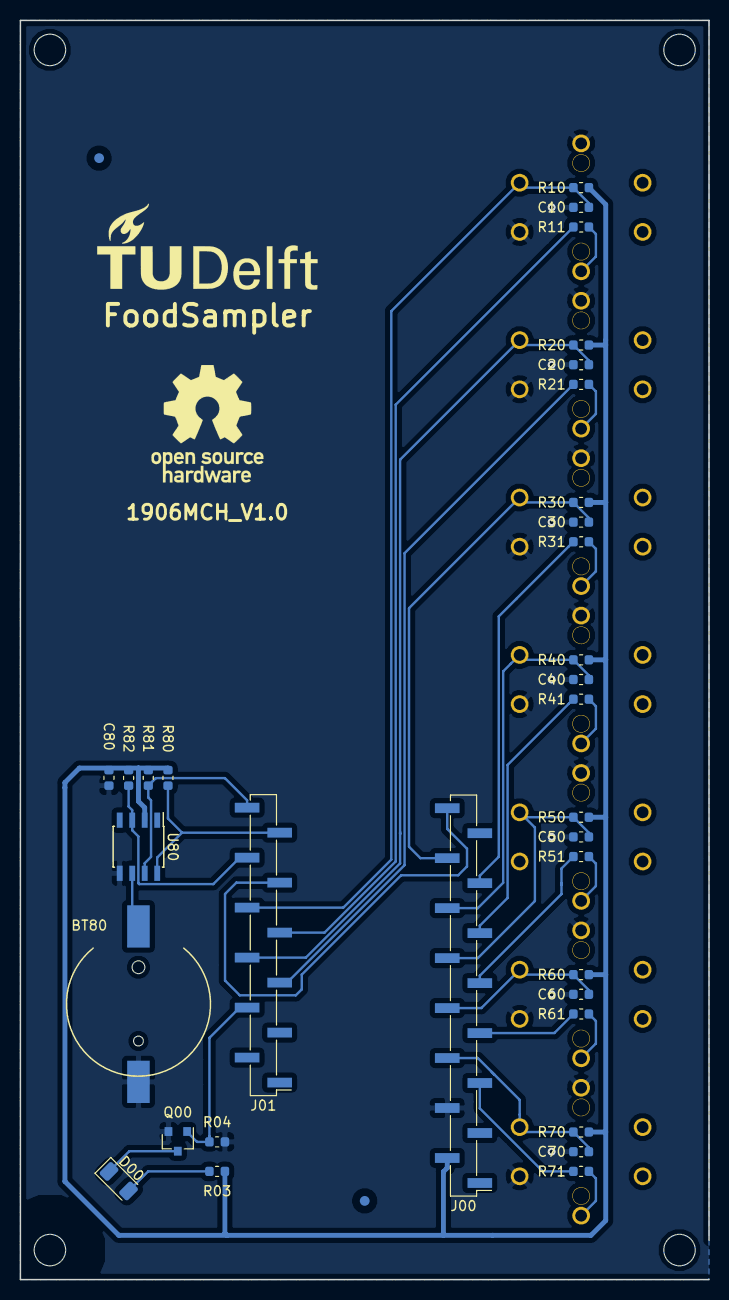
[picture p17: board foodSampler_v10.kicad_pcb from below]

Board: 2 copper layers, 70.0 x 128.0 mm, 40 parts (33 on the bottom side), 31 nets.

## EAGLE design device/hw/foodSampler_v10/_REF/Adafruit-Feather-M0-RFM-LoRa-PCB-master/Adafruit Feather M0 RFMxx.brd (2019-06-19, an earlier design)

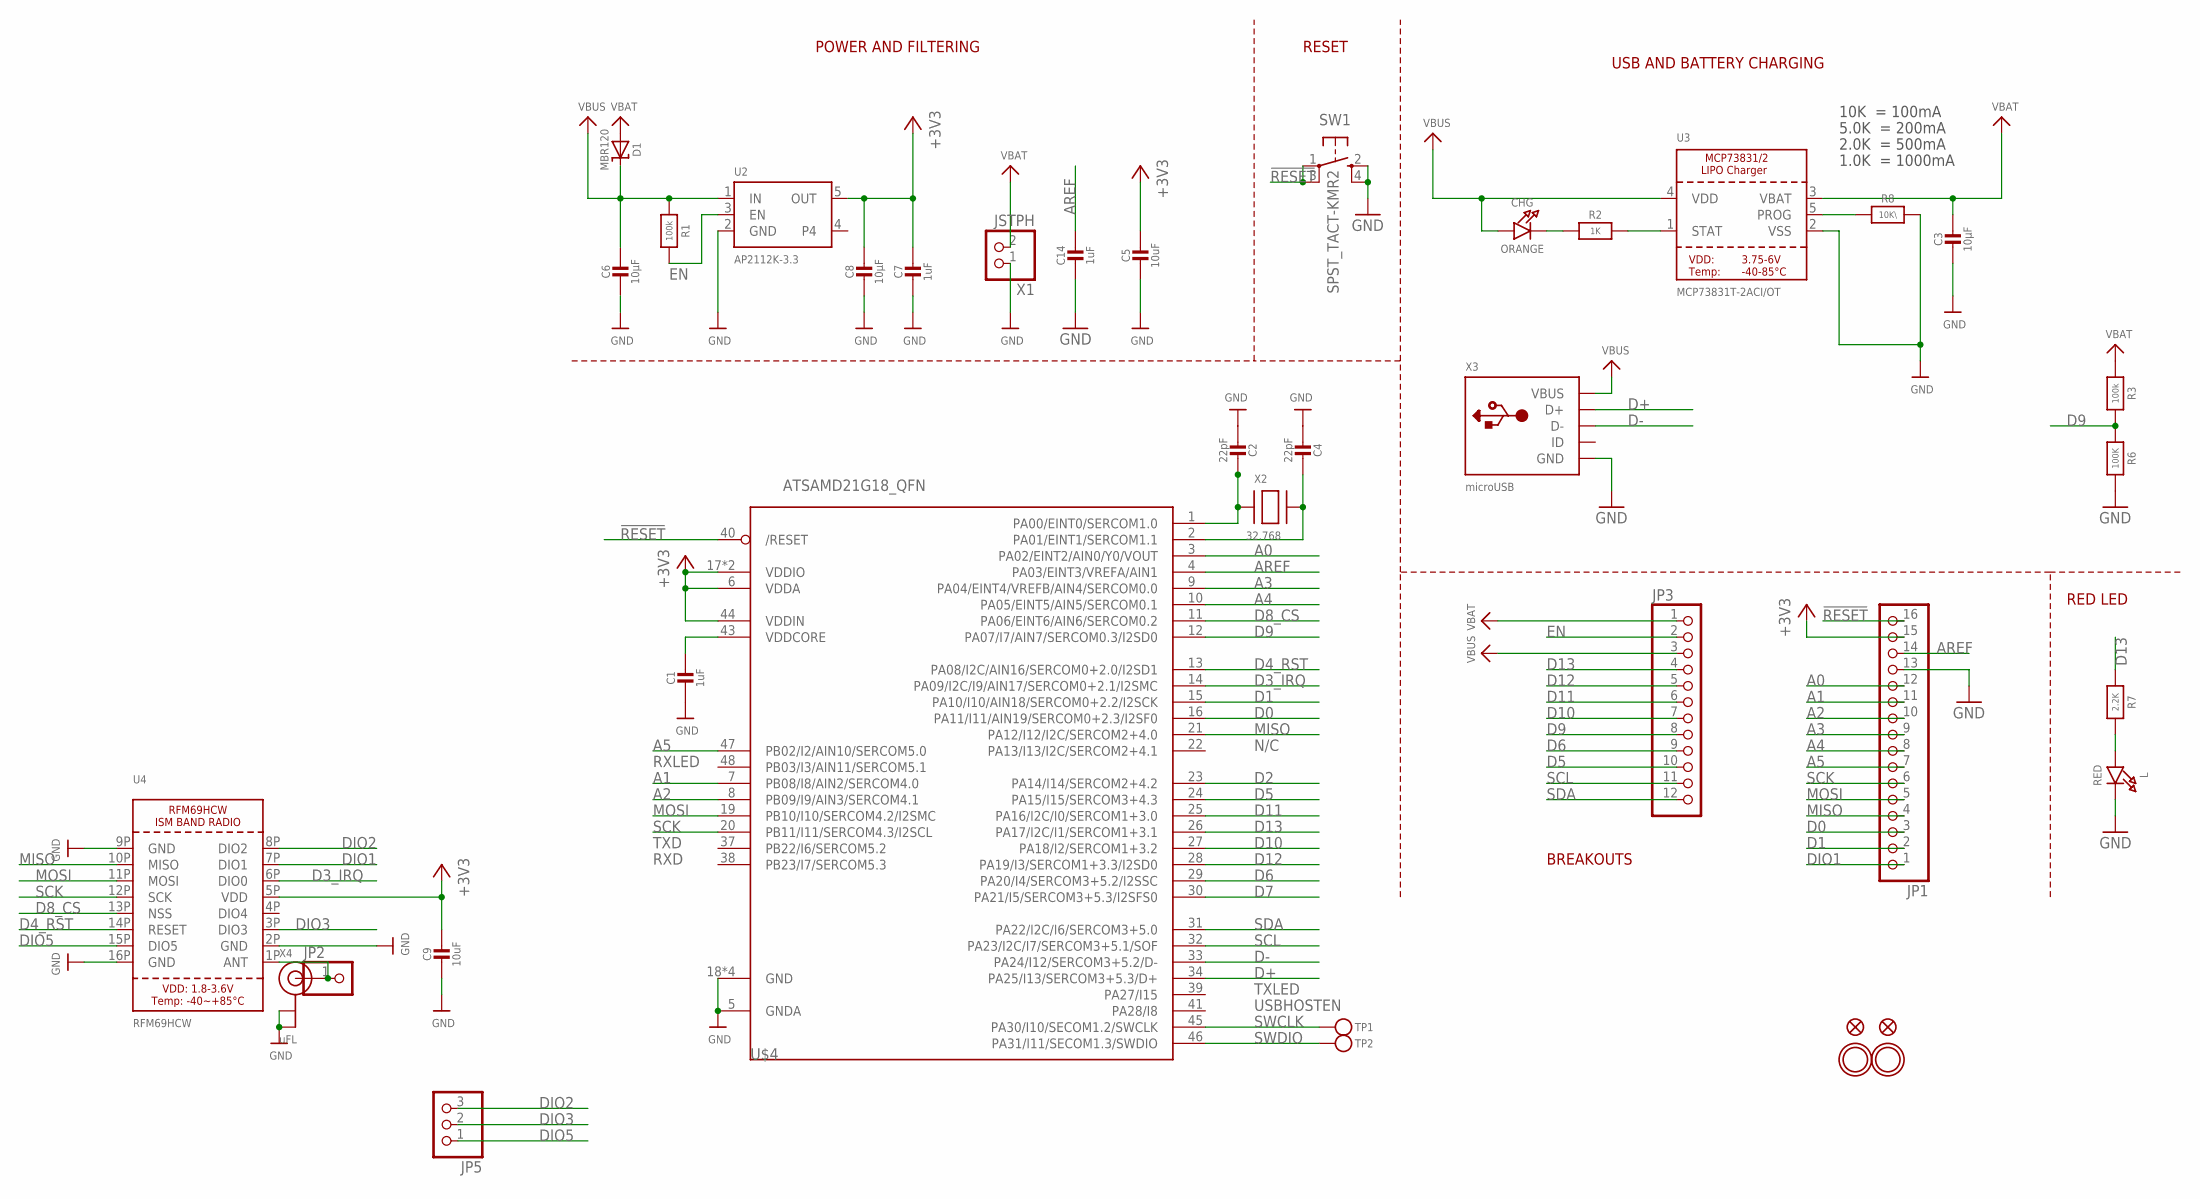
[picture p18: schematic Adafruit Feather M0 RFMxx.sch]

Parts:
C1, C7, C14: 1uF; 0603-NO
C2, C4: 22pF; 0603-NO
C3, C6, C8: 10µF; 0805-NO
C5, C9: 10uF; 0805-NO
CHG: ORANGE; CHIPLED_0805_NOOUTLINE
D1: MBR120; SOD-123
JP1: HEADER-1X16ROUND; 1X16_ROUND
JP2: HEADER-1X1ROUND; 1X01_ROUND
JP3: HEADER-1X12; 1X12_ROUND
JP5: HEADER-1X3ROUND; 1X03_ROUND
L: RED; CHIPLED_0805_NOOUTLINE
R1, R3: 100k; 0603-NO
R2: 1K; 0603-NO
R6: 100K; 0603-NO
R7: 2.2K; 0603-NO
R8: 10K\; 0603-NO
SW1: SPST_TACT-KMR2; KMR2
TP1, TP2: TESTPOINTROUND1.5MM; TESTPOINT_ROUND_1.5MM
U2: AP2112K-3.3; SOT23-5
U3: MCP73831T-2ACI/OT; SOT23-5
U4: RFM69HCW; RFMHCW_SMT
U$4: ATSAMD21G18_QFN; TQFN48_7MM
U$31, U$32: MOUNTINGHOLE2.5; MOUNTINGHOLE_2.5_PLATED
U$34, U$35: FIDUCIAL""; FIDUCIAL_1MM
X1: JSTPH; JSTPH2
X2: 32.768; XTAL3215
X3: microUSB; 4UCONN_20329_V2
X4: uFL; U.FL

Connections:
!RESET: JP1.16, SW1.1, SW1.3 (P1), U$4.40 (/RESET)
+3V3: C5.1, C7.1, C8.1, C9.1, JP1.15, U2.5 (OUT), U4.5P (VDD), U$4.6 (VDDA), U$4.17 (VDDIO), U$4.36 (VDDIO), U$4.44 (VDDIN)
A0: JP1.12, U$4.3 (PA02/EINT2/AIN0/Y0/VOUT)
A1: JP1.11, U$4.7 (PB08/I8/AIN2/SERCOM4.0)
A2: JP1.10, U$4.8 (PB09/I9/AIN3/SERCOM4.1)
A3: JP1.9, U$4.9 (PA04/EINT4/VREFB/AIN4/SERCOM0.0)
A4: JP1.8, U$4.10 (PA05/EINT5/AIN5/SERCOM0.1)
A5: JP1.7, U$4.47 (PB02/I2/AIN10/SERCOM5.0)
ANT: JP2.1, U4.1P (ANT), X4.3 (SIGNAL)
AREF: C14.1, JP1.14, U$4.4 (PA03/EINT3/VREFA/AIN1)
D0: JP1.3, U$4.16 (PA11/I11/AIN19/SERCOM0+2.3/I2SF0)
D1: JP1.2, U$4.15 (PA10/I10/AIN18/SERCOM0+2.2/I2SCK)
D2: U$4.23 (PA14/I14/SERCOM2+4.2)
D3_IRQ: U4.6P (DIO0), U$4.14 (PA09/I2C/I9/AIN17/SERCOM0+2.1/I2SMC)
D4_RST: U4.14P (RESET), U$4.13 (PA08/I2C/AIN16/SERCOM0+2.0/I2SD1)
D5: JP3.10, U$4.24 (PA15/I15/SERCOM3+4.3)
D6: JP3.9, U$4.29 (PA20/I4/SERCOM3+5.2/I2SSC)
D7: U$4.30 (PA21/I5/SERCOM3+5.3/I2SFS0)
D8_CS: U4.13P (NSS), U$4.11 (PA06/EINT6/AIN6/SERCOM0.2)
D9: JP3.8, R3.2, R6.1, U$4.12 (PA07/I7/AIN7/SERCOM0.3/I2SD0)
D10: JP3.7, U$4.27 (PA18/I2/SERCOM1+3.2)
D11: JP3.6, U$4.25 (PA16/I2C/I0/SERCOM1+3.0)
D12: JP3.5, U$4.28 (PA19/I3/SERCOM1+3.3/I2SD0)
D13: JP3.4, R7.1, U$4.26 (PA17/I2C/I1/SERCOM1+3.1)
D+: U$4.34 (PA25/I13/SERCOM3+5.3/D+), X3.D+
D-: U$4.33 (PA24/I12/SERCOM3+5.2/D-), X3.D-
DIO1: JP1.1, U4.7P (DIO1)
DIO2: JP5.3, U4.8P (DIO2)
DIO3: JP5.2, U4.3P (DIO3)
DIO5: JP5.1, U4.15P (DIO5)
EN: JP3.2, R1.2, U2.3 (EN)
GND: C1.2, C2.2, C3.2, C4.2, C5.2, C6.2, C7.2, C8.2, C9.2, C14.2, JP1.13, L.C, R6.2, R8.2, SW1.2 (S), SW1.4 (S1), U2.2 (GND), U3.2 (VSS), U4.2P (GND), U4.9P (GND), U4.16P (GND), U$4.5 (GNDA), U$4.18 (GND), U$4.35 (GND), U$4.42 (GND), U$4.THERMAL (GND), X1.1, X3.BASE@1 (GND), X3.BASE@2 (GND), X3.GND, X3.SPRT@1 (GND), X3.SPRT@2 (GND), X3.SPRT@3 (GND), X3.SPRT@4 (GND), X4.1 (GND), X4.2 (GND)
MISO: JP1.4, U4.10P (MISO), U$4.21 (PA12/I12/I2C/SERCOM2+4.0)
MOSI: JP1.5, U4.11P (MOSI), U$4.19 (PB10/I10/SERCOM4.2/I2SMC)
unnamed: CHG.C, R2.1
unnamed: L.A, R7.2
unnamed: R2.2, U3.1 (STAT)
unnamed: R8.1, U3.5 (PROG)
unnamed: C2.1, U$4.1 (PA00/EINT0/SERCOM1.0), X2.P$1
unnamed: C4.1, U$4.2 (PA01/EINT1/SERCOM1.1), X2.P$2
SCK: JP1.6, U4.12P (SCK), U$4.20 (PB11/I11/SERCOM4.3/I2SCL)
SCL: JP3.11, U$4.32 (PA23/I2C/I7/SERCOM3+5.1/SOF)
SDA: JP3.12, U$4.31 (PA22/I2C/I6/SERCOM3+5.0)
SWCLK: TP1.P$1, U$4.45 (PA30/I10/SECOM1.2/SWCLK)
SWDIO: TP2.P$1, U$4.46 (PA31/I11/SECOM1.3/SWDIO)
VBAT: C3.1, D1.A, JP3.1, R3.1, U3.3 (VBAT), X1.2
VBUS: C6.1, CHG.A, D1.C, JP3.3, R1.1, U2.1 (IN), U3.4 (VDD), X3.VBUS
VDDCORE: C1.1, U$4.43 (VDDCORE)

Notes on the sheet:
POWER AND FILTERING
RESET
10K = 100mA
5.0K = 200mA
2.0K = 500mA
1.0K = 1000mA
N/C
TXLED
USBHOSTEN
RXLED
TXD
RXD
USB AND BATTERY CHARGING
BREAKOUTS
RED LED

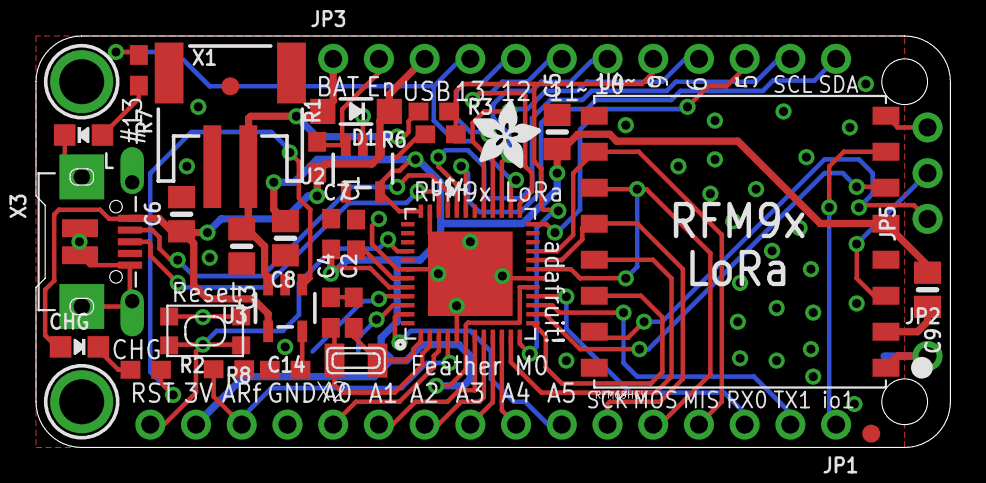
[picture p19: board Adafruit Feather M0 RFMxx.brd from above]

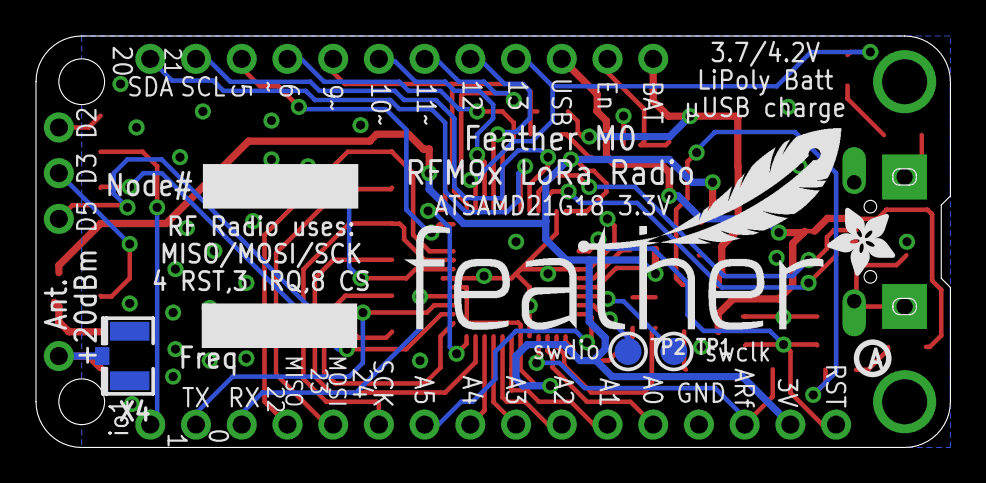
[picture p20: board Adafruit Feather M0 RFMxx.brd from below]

Board: 2 copper layers, 50.8 x 22.9 mm, 42 parts (6 on the bottom side), 46 nets.

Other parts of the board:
U$7, U$12: ADAFRUIT_3.5MM
U$9: FEATHERLOGO
U$13: PCBFEAT-REV-040

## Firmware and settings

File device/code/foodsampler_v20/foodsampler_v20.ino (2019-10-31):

#include <lmic.h>
#include <hal/hal.h>
#include <SPI.h>
#include "ArduinoLowPower.h"
#include "auth.h"


#define FOODSAMPLER_ID 2
#define HEARTBEAT_INTERVAL 60000  //in milliseconds (10 min)
#define DEBUG 0

//#define CUELENGTH 100

#define SETCLOCK 0

#define YEAR  2019
#define MONTH    6
#define DAY     21
#define HOUR    16
#define MIN     41
#define SEC      0

RTCZero rtc;

#define BUT1   5
#define BUT2   11
#define BUT3   0
#define BUT4   1
#define BUT5   A5
#define BUT6   A3
#define BUT7   A1
#define BATPIN A7

#define LED1   10
#define LED2   12
#define LED3   20
#define LED4   21
#define LED5   18
#define LED6   16
#define LED7   A0

#define LED    13

#define CUE_SIZE 50

bool buttonFlag = false;
bool wakeUpFlag = false;

// Schedule TX every this many seconds (might become longer due to duty
// cycle limitations).
const unsigned TX_INTERVAL = 180;

// This EUI must be in little-endian format, so least-significant-byte
// first. When copying an EUI from ttnctl output, this means to reverse
// the bytes. For TTN issued EUIs the last bytes should be 0xD5, 0xB3,
// 0x70.
void os_getArtEui (u1_t* buf) {
  memcpy_P(buf, APPEUI, 8);
}

// This should also be in little endian format, see above.
//static const u1_t PROGMEM DEVEUI[8]=DEVEUI_ARRAY[0];
void os_getDevEui (u1_t* buf) {
  memcpy_P(buf, DEVEUI_ARRAY[FOODSAMPLER_ID], 8);
}

// This key should be in big endian format (or, since it is not really a
// number but a block of memory, endianness does not really apply). In
// practice, a key taken from ttnctl can be copied as-is.
void os_getDevKey (u1_t* buf) {
  memcpy_P(buf, APPKEY, 16);
}

static uint8_t mydata[CUE_SIZE];
uint8_t dataCounter = 0;
static osjob_t sendjob;

long lastFlashUpdateTime = 0;
boolean ledDebugStatus = 0;
int debugLedFleshInterval = 200;
boolean debugLedflashing = false;

void debugLedUpdate() {
  if (debugLedflashing) {
    if (millis() - lastFlashUpdateTime > debugLedFleshInterval) {
      ledDebugStatus = !ledDebugStatus;
      lastFlashUpdateTime = millis();
      digitalWrite(LED, ledDebugStatus);
    }
  }
}

void connectFlash( void ) {
  debugLedFleshInterval = 1000;
  debugLedflashing = true;
}

void sendFlash( void ) {
  debugLedFleshInterval = 100;
  debugLedflashing = true;
}

void stopFlashing() {
  debugLedflashing = false;
}


// Pin mapping for Adafruit Feather M0 LoRa
const lmic_pinmap lmic_pins = {
  .nss = 8,
  .rxtx = LMIC_UNUSED_PIN,
  .rst = 4,
  .dio = {3, 6, LMIC_UNUSED_PIN},
  .rxtx_rx_active = 0,
  .rssi_cal = 8,                 // LBT cal for the Adafruit Feather M0 LoRa, in dB
  .spi_freq = 8000000,
};

void onEvent (ev_t ev) {
  Serial.print(os_getTime());
  Serial.print(": ");
  switch (ev) {
    case EV_SCAN_TIMEOUT:
      Serial.println(F("EV_SCAN_TIMEOUT"));
      break;
    case EV_BEACON_FOUND:
      Serial.println(F("EV_BEACON_FOUND"));
      break;
    case EV_BEACON_MISSED:
      Serial.println(F("EV_BEACON_MISSED"));
      break;
    case EV_BEACON_TRACKED:
      Serial.println(F("EV_BEACON_TRACKED"));
      break;
    case EV_JOINING:
      Serial.println(F("EV_JOINING"));
      connectFlash();
      break;
    case EV_JOINED:
      Serial.println(F("EV_JOINED"));
      {
        u4_t netid = 0;
        devaddr_t devaddr = 0;
        u1_t nwkKey[16];
        u1_t artKey[16];
        LMIC_getSessionKeys(&netid, &devaddr, nwkKey, artKey);
        Serial.print("netid: ");
        Serial.println(netid, DEC);
        Serial.print("devaddr: ");
        Serial.println(devaddr, HEX);
        Serial.print("artKey: ");
        for (int i = 0; i < sizeof(artKey); ++i) {
          Serial.print(artKey[i], HEX);
        }
        Serial.println("");
        Serial.print("nwkKey: ");
        for (int i = 0; i < sizeof(nwkKey); ++i) {
          Serial.print(nwkKey[i], HEX);
        }
        Serial.println("");
      }
      // Disable link check validation (automatically enabled
      // during join, but because slow data rates change max TX
      // size, we don't use it in this example.
      LMIC_setLinkCheckMode(0);
      stopFlashing();


      break;
    /*
      || This event is defined but not used in the code. No
      || point in wasting codespace on it.
      ||
      || case EV_RFU1:
      ||     Serial.println(F("EV_RFU1"));
      ||     break;
    */
    case EV_JOIN_FAILED:
      Serial.println(F("EV_JOIN_FAILED"));
      break;
    case EV_REJOIN_FAILED:
      Serial.println(F("EV_REJOIN_FAILED"));
      break;
    case EV_TXCOMPLETE:
      Serial.println(F("EV_TXCOMPLETE (includes waiting for RX windows)"));
      stopFlashing();
      if (LMIC.txrxFlags & TXRX_ACK)
        Serial.println(F("Received ack"));
      if (LMIC.dataLen) {
        Serial.print(F("Received "));
        Serial.print(LMIC.dataLen);
        Serial.println(F(" bytes of payload"));
      }
      // Schedule next transmission

      // go to sleep mode here.

      os_setTimedCallback(&sendjob, os_getTime() + sec2osticks(TX_INTERVAL), do_send);

      for(int i  =  0; i<100; i++){
        mydata[i]  =  0;
      }
      
      if (!DEBUG) {
        Serial.println("sleepy time");
        //USBDevice.detach();
        digitalWrite(LED, LOW);
       
        LowPower.deepSleep(HEARTBEAT_INTERVAL);
       
     //   wakeUpTimeOut();
      }

      break;
    case EV_LOST_TSYNC:
      Serial.println(F("EV_LOST_TSYNC"));
      break;
    case EV_RESET:
      Serial.println(F("EV_RESET"));
      break;
    case EV_RXCOMPLETE:
      // data received in ping slot
      Serial.println(F("EV_RXCOMPLETE"));
      break;
    case EV_LINK_DEAD:
      Serial.println(F("EV_LINK_DEAD"));
      break;
    case EV_LINK_ALIVE:
      Serial.println(F("EV_LINK_ALIVE"));
      break;
    /*
      || This event is defined but not used in the code. No
      || point in wasting codespace on it.
      ||
      || case EV_SCAN_FOUND:
      ||    Serial.println(F("EV_SCAN_FOUND"));
      ||    break;
    */
    case EV_TXSTART:
      Serial.println(F("EV_TXSTART"));
      break;
    default:
      Serial.print(F("Unknown event: "));
      Serial.println((unsigned) ev);
      break;
  }
}

void saveBattery(){
  uint16_t bat = readBattery();
    mydata[0] = bat >> 8;
    mydata[1] = bat;
}

void do_send(osjob_t* j) {
  // Check if there is not a current TX/RX job running
  if (LMIC.opmode & OP_TXRXPEND) {
    Serial.println(F("OP_TXRXPEND, not sending"));
  } else {
    // Prepare upstream data transmission at the next possible time.
    LMIC_setTxData2(1, mydata, sizeof(mydata), 0);
    Serial.println(F("Packet queued"));
  }
  // Next TX is scheduled after TX_COMPLETE event.
}


void addToCue(uint8_t hour, uint8_t min, uint8_t button){
  mydata[dataCounter+2] = hour;
  mydata[dataCounter+3] = min;
  mydata[dataCounter+3] = button;
  dataCounter += 3;
  printCue();
}

void printCue(){
  for(int i = 0; i < CUE_SIZE; i++){
    Serial.println(mydata[i]);
  }
}

void setup() {

  if (DEBUG) {
    while (!Serial);
  }

  while (!Serial);
  
  Serial.begin(9600);
  Serial.println(F("Starting"));

  pinMode(BUT1, INPUT_PULLUP);
  pinMode(BUT2, INPUT_PULLUP);
  pinMode(BUT3, INPUT_PULLUP);
  pinMode(BUT4, INPUT_PULLUP);
  pinMode(BUT5, INPUT_PULLUP);
  pinMode(BUT6, INPUT_PULLUP);
  pinMode(BUT7, INPUT_PULLUP);
  pinMode(LED, OUTPUT);
  pinMode(LED1, OUTPUT);
  pinMode(LED2, OUTPUT);
  pinMode(LED3, OUTPUT);
  pinMode(LED4, OUTPUT);
  pinMode(LED5, OUTPUT);
  pinMode(LED6, OUTPUT);
  pinMode(LED7, OUTPUT);

  //    digitalWrite(LED1, HIGH);
  //    digitalWrite(LED2, HIGH);
  //    digitalWrite(LED3, HIGH);
  //    digitalWrite(LED4, HIGH);
  //    digitalWrite(LED5, HIGH);
  //    digitalWrite(LED6, HIGH);
  //    digitalWrite(LED7, HIGH);

  pinMode(BATPIN, INPUT);

  LowPower.attachInterruptWakeup(BUT1, wakeUpButton, FALLING);
  LowPower.attachInterruptWakeup(BUT2, wakeUpButton, FALLING);
  LowPower.attachInterruptWakeup(BUT3, wakeUpButton, FALLING);
  LowPower.attachInterruptWakeup(BUT4, wakeUpButton, FALLING);
  LowPower.attachInterruptWakeup(BUT5, wakeUpButton, FALLING);
  LowPower.attachInterruptWakeup(BUT6, wakeUpButton, FALLING);
  LowPower.attachInterruptWakeup(BUT7, wakeUpButton, FALLING);

  Serial.print("Battery: "); Serial.print(readBattery()); Serial.println(" mV");

  
  rtc.begin();
  if ( SETCLOCK ) {
    rtc.setDate( DAY, MONTH, YEAR );
    rtc.setTime( HOUR, MIN, SEC );
  }



  // LMIC init
  os_init();
  // Let LMIC compensate for +/- 1% clock error
  LMIC_setClockError(MAX_CLOCK_ERROR * 1 / 100);

  // Reset the MAC state. Session and pending data transfers will be discarded.
  LMIC_reset();

  // Start job (sending automatically starts OTAA too)
  do_send(&sendjob);
  //sendFlash();
}

volatile int buttons = 0;

void loop() {
  os_runloop_once();
  debugLedUpdate();
  
  if ( buttonFlag ) {
    //noInterrupts();
    digitalWrite(LED, HIGH);
    buttonFlag = false;

    //delay(20); //just to do some debouncing
    buttons = 0x00;
    buttons |= (!digitalRead(BUT1));
    buttons |= (!digitalRead(BUT2)) << 1;
    buttons |= (!digitalRead(BUT3)) << 2;
    buttons |= (!digitalRead(BUT4)) << 3;
    buttons |= (!digitalRead(BUT5)) << 4;
    buttons |= (!digitalRead(BUT6)) << 5;
    buttons |= (!digitalRead(BUT7)) << 6;
    delay(50);
    //interrupts();
    //Serial.println(buttons);
    //
    Serial.print(rtc.getYear() + 1984); Serial.print("/"); Serial.print(rtc.getMonth()); Serial.print("/"); Serial.print(rtc.getDay()); Serial.print(" ");
    Serial.print(rtc.getHours()); Serial.print(":"); Serial.print(rtc.getMinutes()); Serial.print(":"); Serial.println(rtc.getSeconds());
    
    //addToCue(rtc.getHours(), rtc.getMinutes(), buttons);

    //do_send(&sendjob);

    //sendFlash();
    delay(50);
    digitalWrite(LED, LOW);
    
  }

  if ( wakeUpFlag && !buttonFlag ) {
    
    saveBattery();
    dataCounter =  0;
    
    wakeUpFlag = false;
    do_send(&sendjob);
    //addToCue(mydata[0], mydata[1], mydata[2]);
    //sendFlash();

    //processCue();

  }
}

void wakeUpTimeOut() {
  if ( !buttonFlag  ) {
    wakeUpFlag =  true;
  }
}

void wakeUpButton() {
  //digitalWrite(LED, HIGH);
  buttonFlag = true;
}



uint16_t readBattery() {

  float measuredvbat = analogRead(BATPIN);

  measuredvbat *= 2;     // we divided by 2, so multiply back
  measuredvbat *= 3.3;   // Multiply by 3.3V, our reference voltage
  measuredvbat /= 1024;  // convert to voltage
  uint16_t batVoltage = measuredvbat *= 1000;
  //Serial.print("VBat: " ); Serial.println(batVoltage);

  return ( batVoltage );
}

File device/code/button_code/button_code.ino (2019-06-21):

#include "ArduinoLowPower.h"

#define BUT0   9
#define BUT1   11
#define BUT2   0
#define BUT3   23
#define BUT4   A5
#define BUT5   A3
#define BUT6   A1
#define BATPIN A7
#define LED    13

bool intFlag = false;


void setup() {
  // put your setup code here, to run once:
  Serial.begin(9600);
  while ( !Serial );

  Serial.println("FoodSampler, ready to sample some food");

  pinMode(BUT0, INPUT);
  pinMode(BUT1, INPUT);
  pinMode(BUT2, INPUT);
  pinMode(BUT3, INPUT);
  pinMode(BUT4, INPUT);
  pinMode(BUT5, INPUT);
  pinMode(BUT6, INPUT);
  pinMode(LED, OUTPUT);
  pinMode(BATPIN, INPUT);


  digitalWrite(LED, LOW);

  //  attachInterrupt(digitalPinToInterrupt(BUT0), readButtons, RISING);
  //  attachInterrupt(digitalPinToInterrupt(BUT1), readButtons, RISING);
  //  attachInterrupt(digitalPinToInterrupt(BUT2), readButtons, RISING);
  //  attachInterrupt(digitalPinToInterrupt(BUT3), readButtons, RISING);
  //  attachInterrupt(digitalPinToInterrupt(BUT4), readButtons, RISING);
  //  attachInterrupt(digitalPinToInterrupt(BUT5), readButtons, RISING);
  //  attachInterrupt(digitalPinToInterrupt(BUT6), readButtons, RISING);

  LowPower.attachInterruptWakeup(BUT0, wakeyWakey, RISING);
  LowPower.attachInterruptWakeup(BUT1, wakeyWakey, RISING);
  LowPower.attachInterruptWakeup(BUT2, wakeyWakey, RISING);
  LowPower.attachInterruptWakeup(BUT3, wakeyWakey, RISING);
  LowPower.attachInterruptWakeup(BUT4, wakeyWakey, RISING);
  LowPower.attachInterruptWakeup(BUT5, wakeyWakey, RISING);
  LowPower.attachInterruptWakeup(BUT6, wakeyWakey, RISING);

  LowPower.deepSleep();
}

volatile int buttons = 0;

void loop() {
  // put your main code here, to run repeatedly:





  //Serial.println(buttons);
  //Serial.println(digitalRead(BUT0));
  //delay(100);
  //buttons = 0x00;

  if ( intFlag ) {

    //noInterrupts();
    intFlag = false;
    delay(5000);

    readBattery();

    buttons |= (digitalRead(BUT0));
    buttons |= (digitalRead(BUT1)) << 1;
    buttons |= (digitalRead(BUT2)) << 2;
    buttons |= (digitalRead(BUT3)) << 3;
    buttons |= (digitalRead(BUT4)) << 4;
    buttons |= (digitalRead(BUT5)) << 5;
    buttons |= (digitalRead(BUT6)) << 6;
    delay(50);
    //interrupts();
    Serial.print("Buttons: " ); Serial.println(buttons);
    buttons = 0x00;

    delay(2000);
    digitalWrite(LED, LOW);
    LowPower.deepSleep();
  }
}

uint16_t readBattery() {

  float measuredvbat = analogRead(BATPIN);

  measuredvbat *= 2;    // we divided by 2, so multiply back
  measuredvbat *= 3.3;  // Multiply by 3.3V, our reference voltage
  measuredvbat /= 1024; // convert to voltage
  uint16_t batVoltage = measuredvbat *= 1000;
  Serial.print("VBat: " ); Serial.println(batVoltage);
  return ( batVoltage );


}

//void readButtons(){
//  intFlag = true;
//}

void wakeyWakey() {
  digitalWrite(LED, HIGH);
  intFlag = true;
}

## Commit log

2019-04-26 done parsing data from device - need to modify device property in rest api
2019-05-15 added mosca broker and code to forward messages to mqtt
    [test_ttn_device.ino]
2019-05-15 Added working protoype code
    [foodSampler_v10.kicad_pcb, foodSampler_v10.sch]
2019-06-19 schematic added
2019-06-21 tryign to fix things
    [foodSampler_v10.sch, foodsampler.stl]
2019-06-21 V1.0, all working
    [_saved_foodSampler_v10.sch]
2019-06-21 led solved
2019-06-21 led solved + flash sequences
    [foodsampler_v10.ino]
2019-06-21 fixes server crashing when data is coming from unknown device
2019-07-01 regenerated doc
    [_saved_foodSampler_v10.sch]
2019-07-02 add filter mechanism for api
2019-08-20 fixes filter events by date range
2019-10-03 created new case
    [rev2.stl]
2019-10-28 updated 3d printed files
    [rev3.stl, rev3b.stl, rev3c.3dm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]
2019-10-28 provisioned all the devices id
2019-10-28 add nickname to device
2019-10-30 to compare
    [foodSampler_v10.kicad_pcb]
2019-11-01 fixes to the main logic
    [cueUtils.ino, foodsampler_v11.ino, lmicUtils.ino]
2019-11-11 fixes data loss by forcing hack form ttn
    [foodsampler_v11.ino, lmicUtils.ino]
2021-04-13 added hw v2.0
    [foodSampler_v20-B.Cu.gbr, foodSampler_v20-B.Mask.gbr, foodSampler_v20-B.Paste.gbr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]
2021-05-21 V2.1 added
    [foodSampler_v20.csv, foodSampler_v20.kicad_pcb, foodSampler_v21.kicad_pcb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]
2021-06-10 _sampler V2.2 added
    [foodSampler_v21-B_Cu.gbr, foodSampler_v21-B_Mask.gbr, foodSampler_v21-B_Paste.gbr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]
2021-06-15 small revisions
    [foodSampler_v22.sch]

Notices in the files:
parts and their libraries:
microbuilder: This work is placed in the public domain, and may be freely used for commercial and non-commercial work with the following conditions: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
